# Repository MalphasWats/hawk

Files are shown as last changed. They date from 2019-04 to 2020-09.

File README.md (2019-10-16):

# hawk
Small ARM dev board based on ATSAMD10.

This repository takes a step-by-step look at creating a simple ATSAMD10-based dev-board using KiCAD.

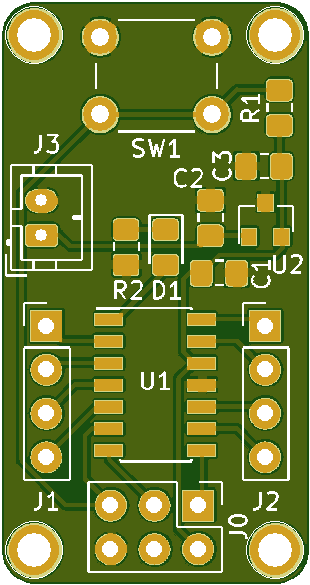
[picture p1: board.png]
Board


## Contents

### Designing the PCB

1. [Getting Started - Creating a Schematic.](https://github.com/MalphasWats/hawk/blob/master/articles/creating-the-schematic.markdown)
2. [Adding Battery Power.](https://github.com/MalphasWats/hawk/blob/master/articles/adding-battery-power.markdown)
3. [Footprints & Net-lists.](https://github.com/MalphasWats/hawk/blob/master/articles/footprints-and-netlists.markdown)
4. [Creating a PCB.](https://github.com/MalphasWats/hawk/blob/master/articles/creating-a-pcb.markdown)
5. [Aside: Designing a Board Outline.](https://github.com/MalphasWats/hawk/blob/master/articles/designing-board-outline.markdown)
6. [Component Layout.](https://github.com/MalphasWats/hawk/blob/master/articles/component-layout.markdown)
7. [Laying Traces.](https://github.com/MalphasWats/hawk/blob/master/articles/laying-traces.markdown)
8. [Filled Zones.](https://github.com/MalphasWats/hawk/blob/master/articles/filling-zones.markdown)
9. [Silkscreen.](https://github.com/MalphasWats/hawk/blob/master/articles/silkscreen.markdown)
10. [PCB Manufacture.](https://github.com/MalphasWats/hawk/blob/master/articles/pcb-manufacture.markdown)

### Assembly
11. [Assembly.](https://github.com/MalphasWats/hawk/blob/master/articles/assembly.markdown)

### Programming

...

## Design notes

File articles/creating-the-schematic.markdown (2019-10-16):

# Creating the schematic

I'm using KiCAD for this project. It's free and it more than does the job. I'm sure people have various Strong Opinions on which EDA software is the best, but I'm also sure that they're all wrong, regardless of which one they think is best.

Open up KiCAD and create a new project:

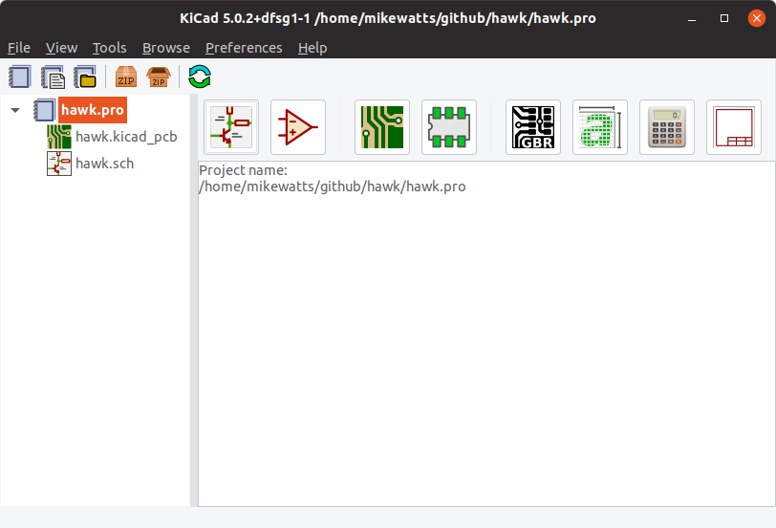
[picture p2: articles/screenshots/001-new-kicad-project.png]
New KiCAD Project


I've named this project *Hawk*. My projects generally get named when I make them a repository in [GitHub](https://github.com/MalphasWats). I think I wanted a name that suggested 'dev-board' and had recently read a tweet about Tony Hawk, who is a skate*board*er. Welcome, reader, to the inside of my brain.

We'll start by creating a Schematic for our board:

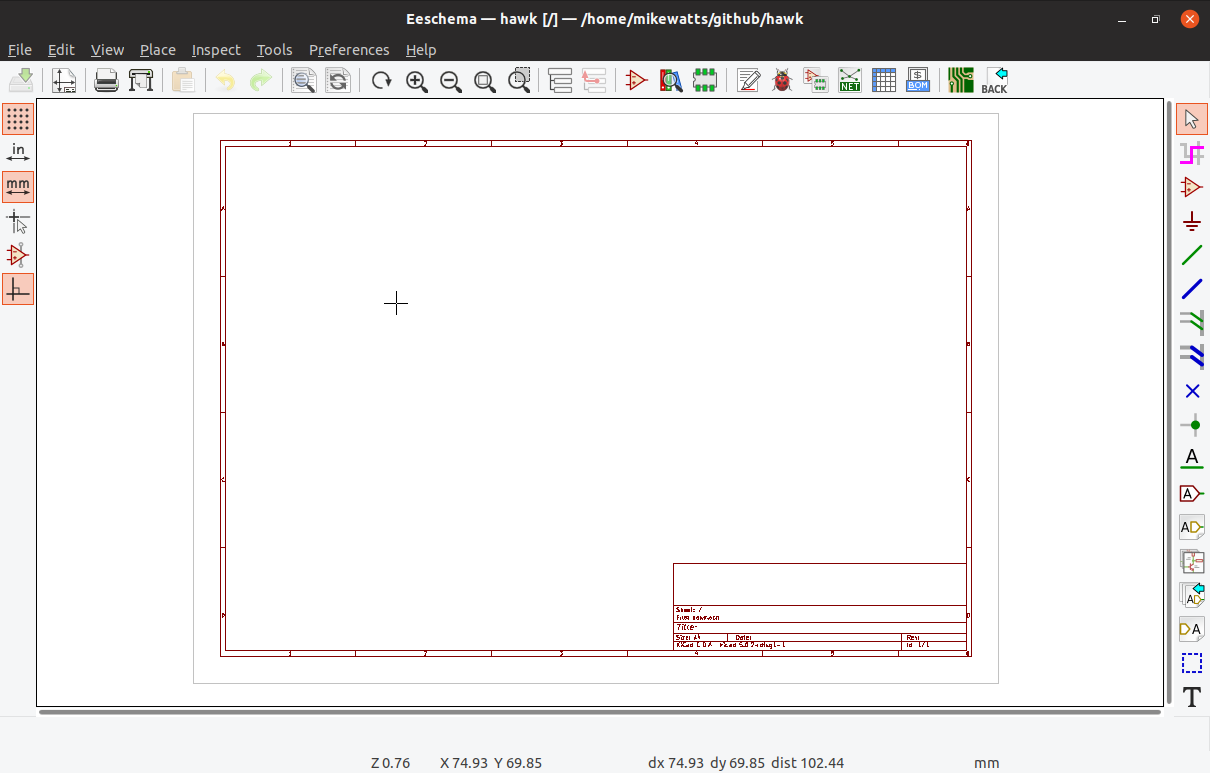
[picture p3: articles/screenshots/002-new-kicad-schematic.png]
New KiCAD Schematic


Ok, we have a nice blank schematic. Press the *A* key to add a *symbol*. This brings up the symbol browser:

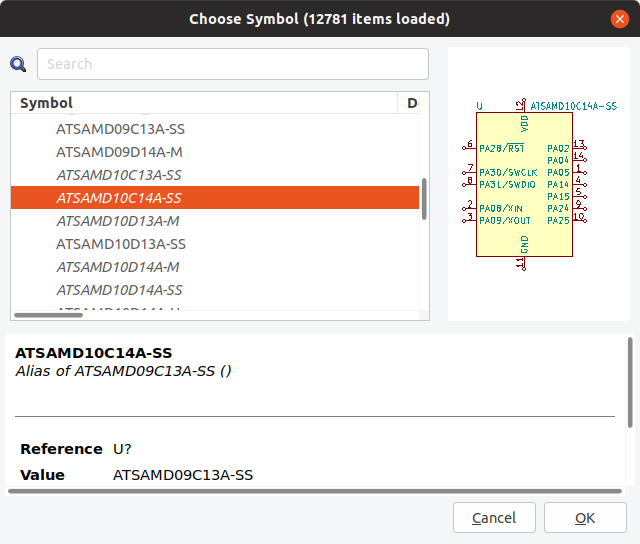
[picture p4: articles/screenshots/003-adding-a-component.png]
Symbol Browser


Now, this is where things go immediately off the rails - the basic installation of KiCAD does not have a symbol for the Microcontroller we're using in this project. You can download these symbols from the [KiCAD GitHub Symbol Library](https://kicad.github.io/symbols/).

Once you've downloaded the correct library [ (MCU Microchip SAMD) ](https://kicad.github.io/symbols/MCU_Microchip_SAMD), choose *Manage Symbol Libraries...* from the *Preferences* menu, then click the *Browse Libraries...* button to add the downloaded library.

Now you should be able to find the ATSAMD10C14 symbol shown in the screenshot. This is the only 'non-standard' component we'll be using for this project.

Double click the symbol in the list and the browser window closes and the symbol is attached to your mouse. Click anywhere on the page to add the symbol to the schematic.

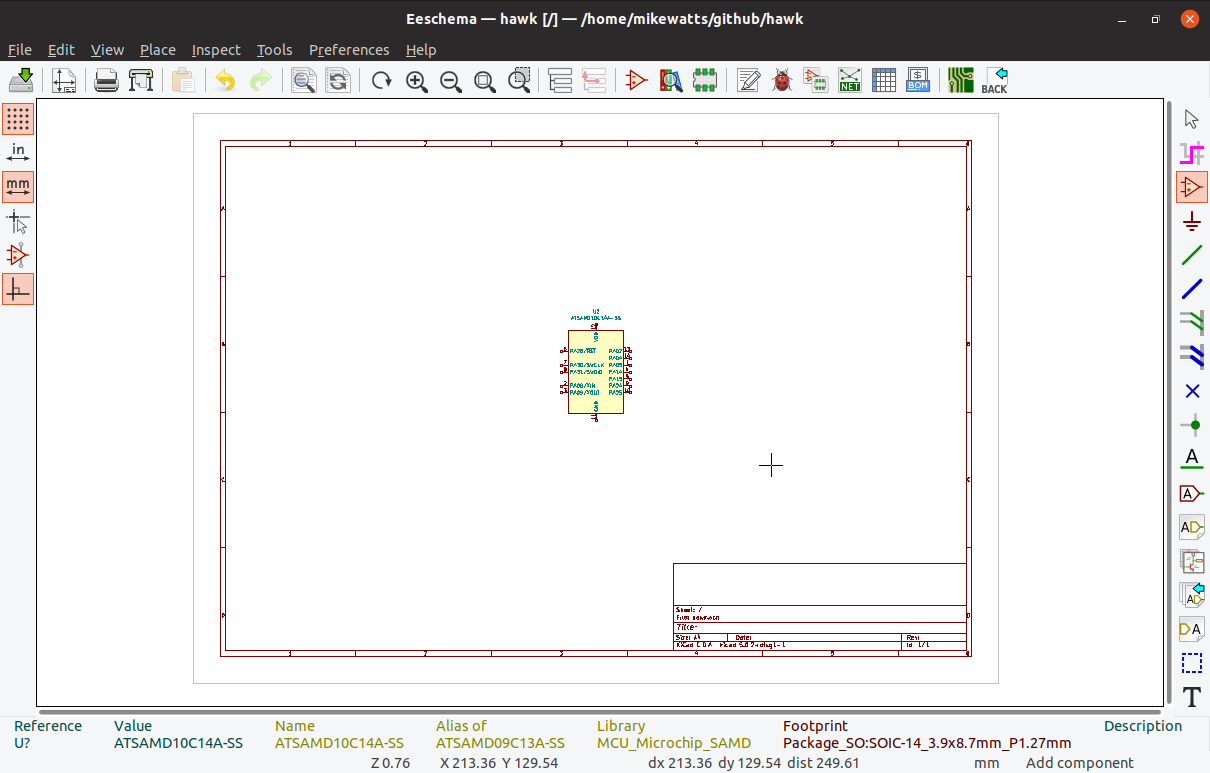
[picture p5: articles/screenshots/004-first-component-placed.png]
Symbol Placed


Congratulations, you've made a schematic! It doesn't really do very much yet though. Let's add a bypass capacitor for the MCU IC.

When we pressed *A* earlier, we selected the *Place Symbol* tool, that means we just have to click anywhere on the schematic page to add another symbol. KiCAD puts passive components like capacitors and resistors in the *Devices* section of the symbol library browser:

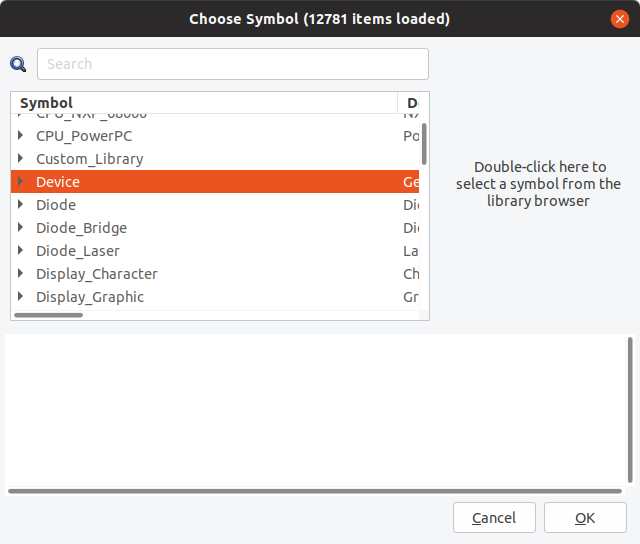
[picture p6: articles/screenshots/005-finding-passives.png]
Finding Passives


Expand it and find the *C* symbol (I prefer to use the *C_Small* version, but either will do.).

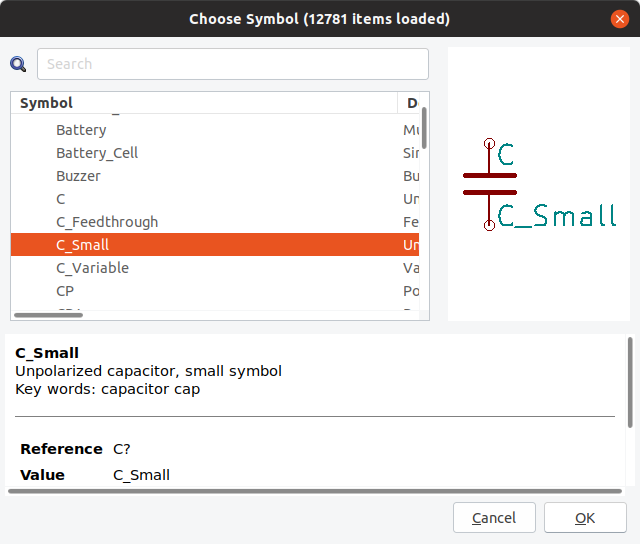
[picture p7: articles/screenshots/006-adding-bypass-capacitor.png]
Bypass Capacitor


Double click to select the symbol then click where you want to place it on the schematic page:

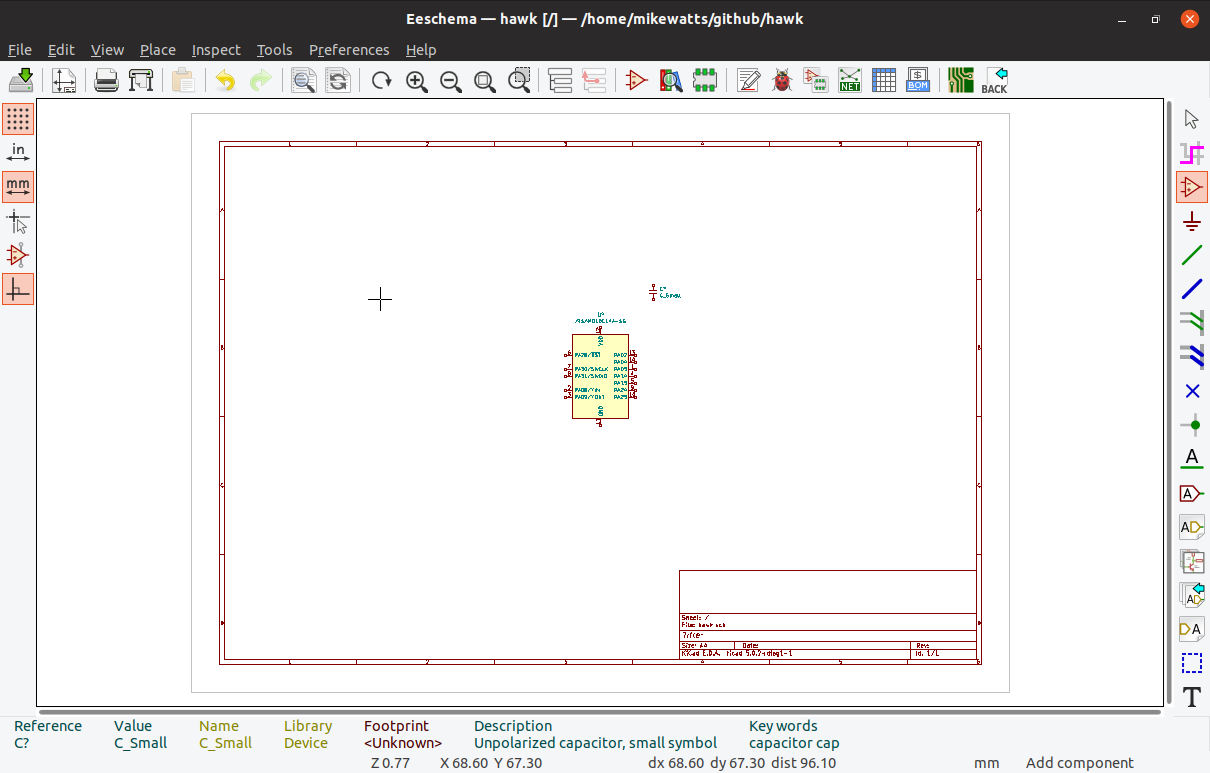
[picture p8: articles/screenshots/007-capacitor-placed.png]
Capacitor Placed


I tend to use 0.1uF capacitors for bypassing ICs, I'm sure the internet is replete with screeds on why a different value is better. Frankly, most of my projects work without even bothering to solder the thing to the board.

Bring your mouse over the capacitor *Value Field*, if you chose the regular symbol version it will just be a capital *C*, otherwise it'll say *C_Small*. With your mouse over the field, press the *E* key on your keyboard to bring up the field editor.

Enter the new value for your capacitor and press *OK*.

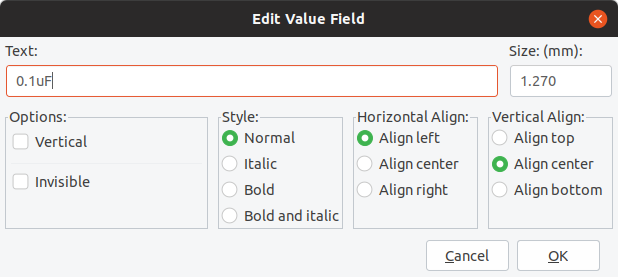
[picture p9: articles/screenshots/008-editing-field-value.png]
Edit the field value


We'll connect the capacitor to the power net next. Press *P* on the keyboard to bring up the *Power Symbol Browser*.

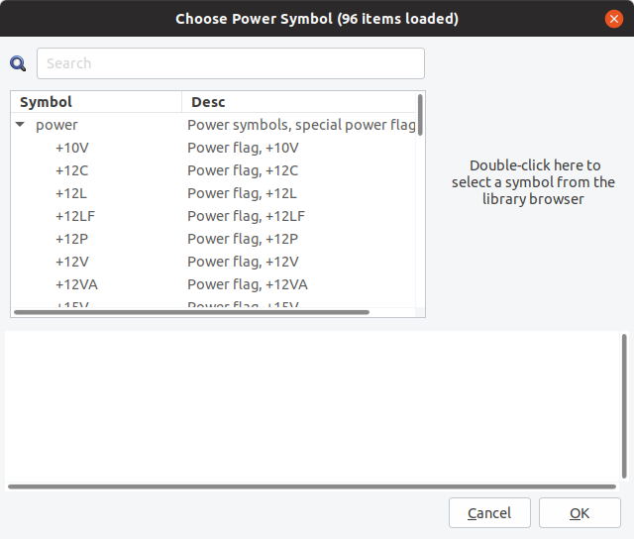
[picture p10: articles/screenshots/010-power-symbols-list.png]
Power Symbol Browser


Expand the *power* list and scroll down to find +3V3. Double click it to select.

Now, instead of just clicking on an empty spot on the schematic, attach the symbol to the lead sticking out of the top of the capacitor symbol.

Press *P* again and scroll down to place a *GND* symbol. Attach it to the bottom lead of the capacitor symbol.

Once you have symbols placed on the schematic, you can duplicate them by hovering over them and pressing the *C* key. Duplicate the +3V3 symbol and the GND symbol to attach them to the relevant leads of the MCU.

You'll also notice in the screenshot below that I've moved the labels for the MCU. You can do this by hovering your mouse over them and pressing *M*.

*M*, *C*, *A* and *P* are super useful shortcuts for laying out schematics. They become muscle memory quite quickly.

Using the *scroll-wheel* on the mouse lets you zoom in so  you can actually see what you're doing. As far as I've managed to work out, zooming like this centres the zoom wherever your mouse pointer is.

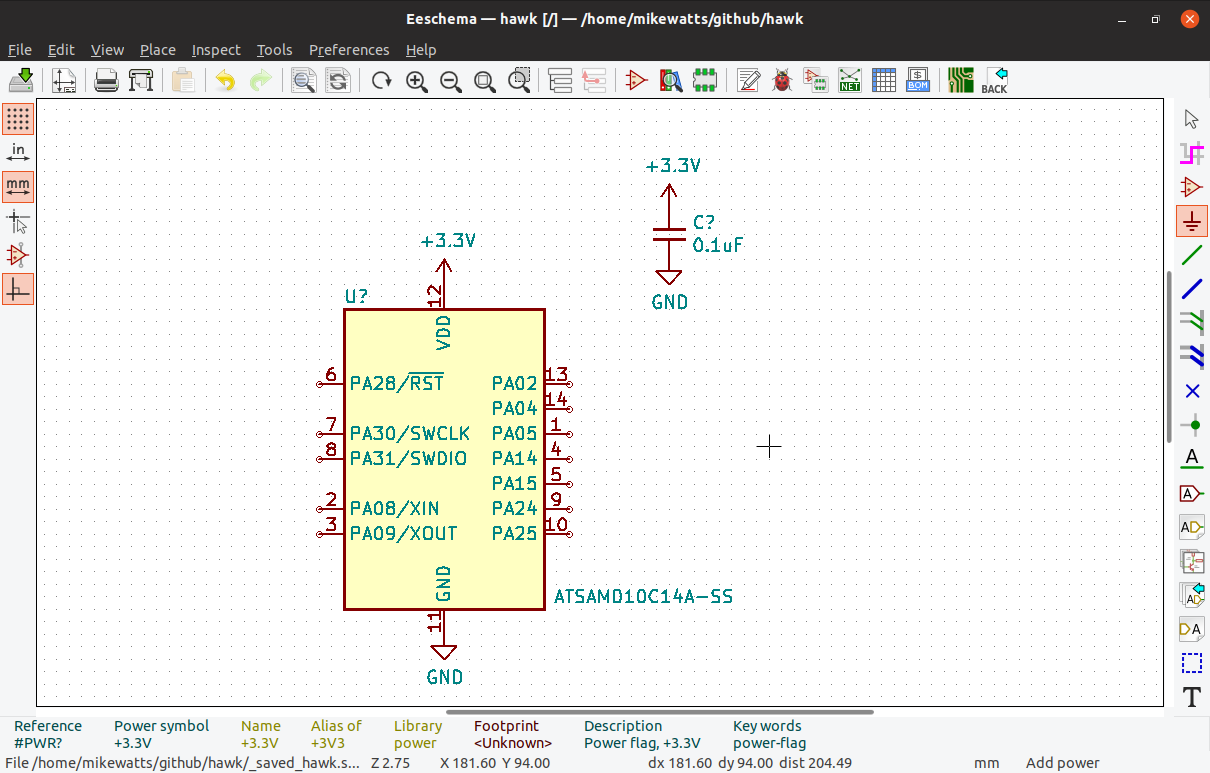
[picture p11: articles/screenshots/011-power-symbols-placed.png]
Place Power Symbols


Notice that the capacitor and MCU aren't connected directly, we've just connected them to the power net, it'll be up to us to place them sensibly on the PCB so that the capacitor can do its job.

Ok, let's create a reset circuit. First, we want to add a *pull-up* resistor to the MCU's reset pin. If we simply leave the pin floating, the MCU could behave strangely as our circuit gets subjected to electromagnetic interference.

We'll start by labelling the reset pin. I use *global* labels because I think they make a schematic more readable. Choose *Global Label* from the *Place* menu and then click on the end of the lead for *pin 6* to bring up the label pane:

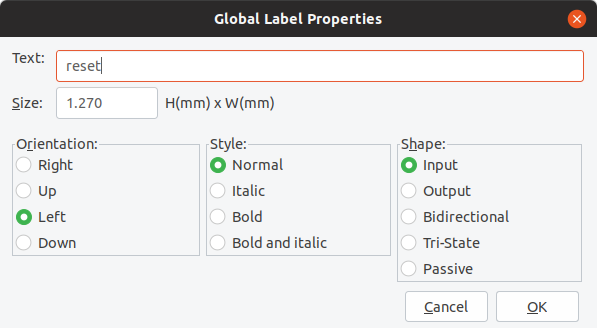
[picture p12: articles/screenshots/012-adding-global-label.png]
Adding a global label


Give the label a sensible name and make sure *Left* is chosen for *Orientation*. Click *OK* and then click the mouse on the end of the *pin 6* lead to attach the label to it.

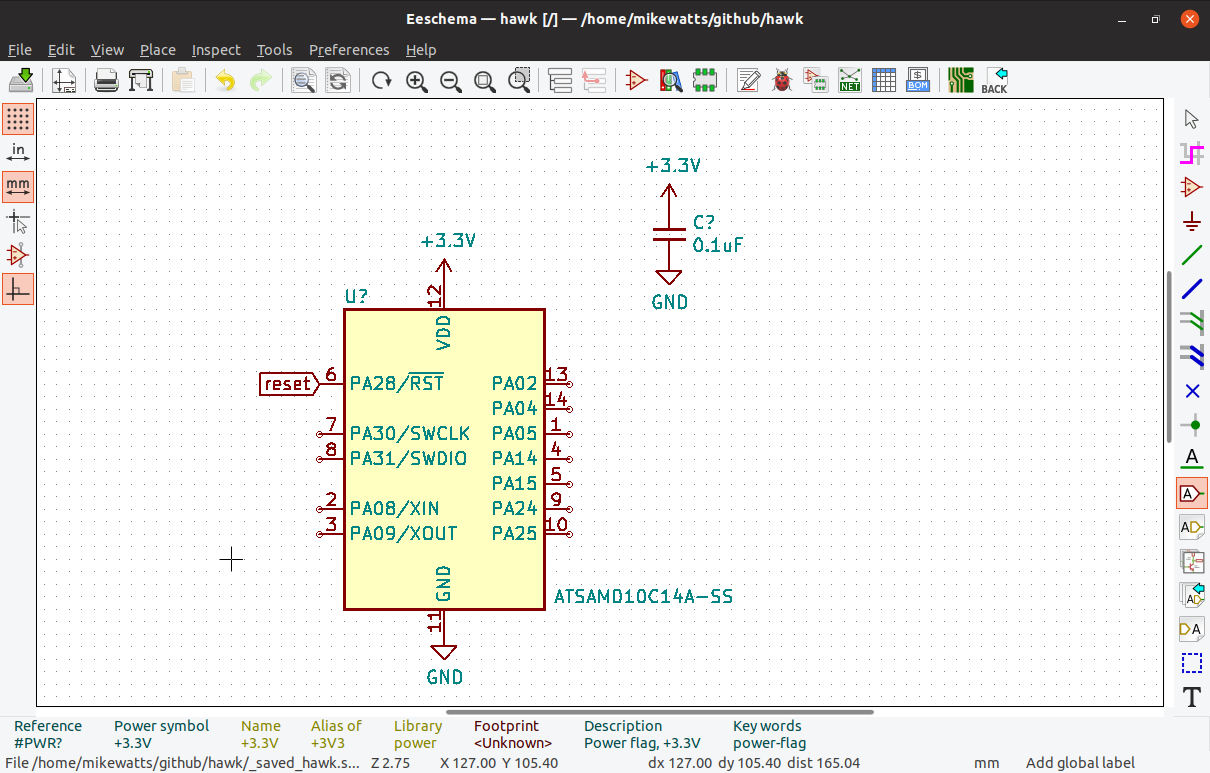
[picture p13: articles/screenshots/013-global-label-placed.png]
Place the label


Whilst we're at it, let's add 2 more labels for the programming pins, we're already in *Label Place mode* so we just need to click on the schematic to add a new label:

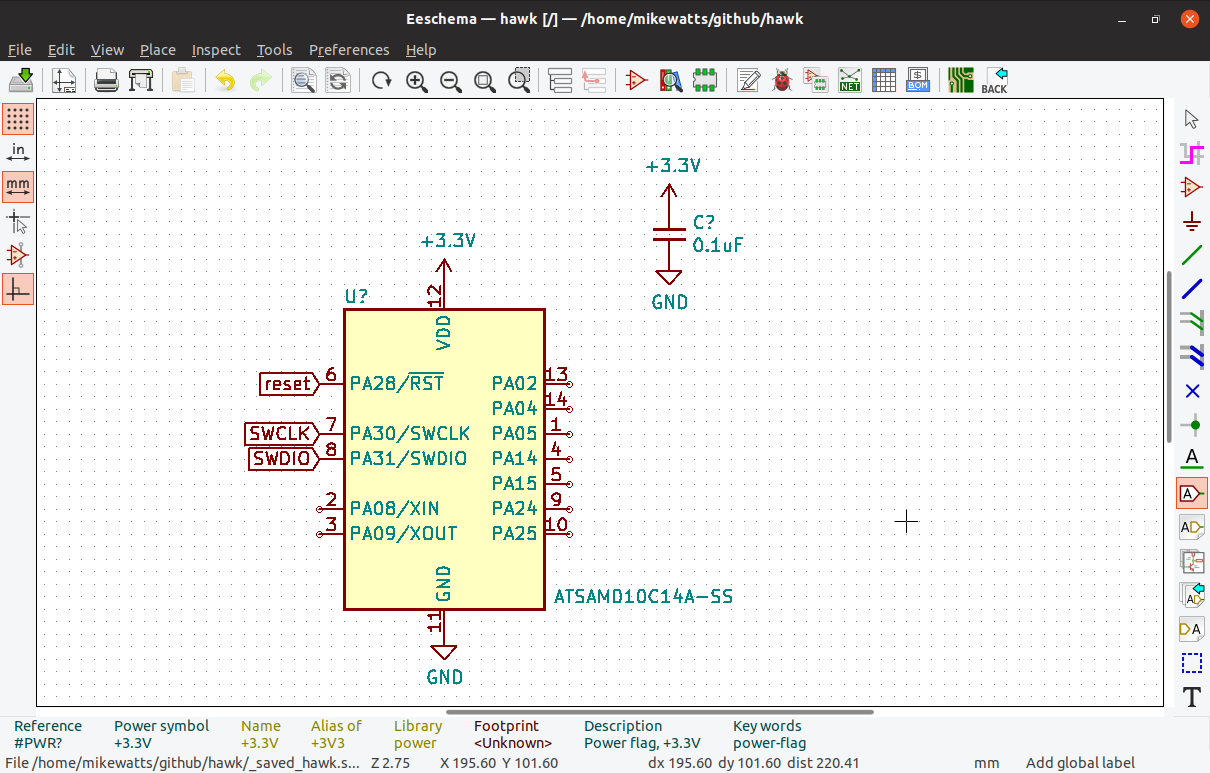
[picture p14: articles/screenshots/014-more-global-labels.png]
Programming pin labels
.

Next let's add the pull-up resistor. Press *A* to go back into symbol placing mode and bring up the symbol browser. You'll find it in the *Devices* section again, called simply *R*.

Click to place it, then use the *C* shortcut to copy the 3V3 power symbol and attach it to the top lead of the resistor. Use *C* again to copy the *reset* label from the MCU pin 6.

With the *reset* label attached to the mouse, press the *R* key to rotate it 90 degrees. Press the *R* key until the label is pointing *up* and attach it to the bottom lead of the resistor.

Finally, hover over the bottom *R* label, press *E* and add a suitable resistance value - I tend to use 10K ohm:

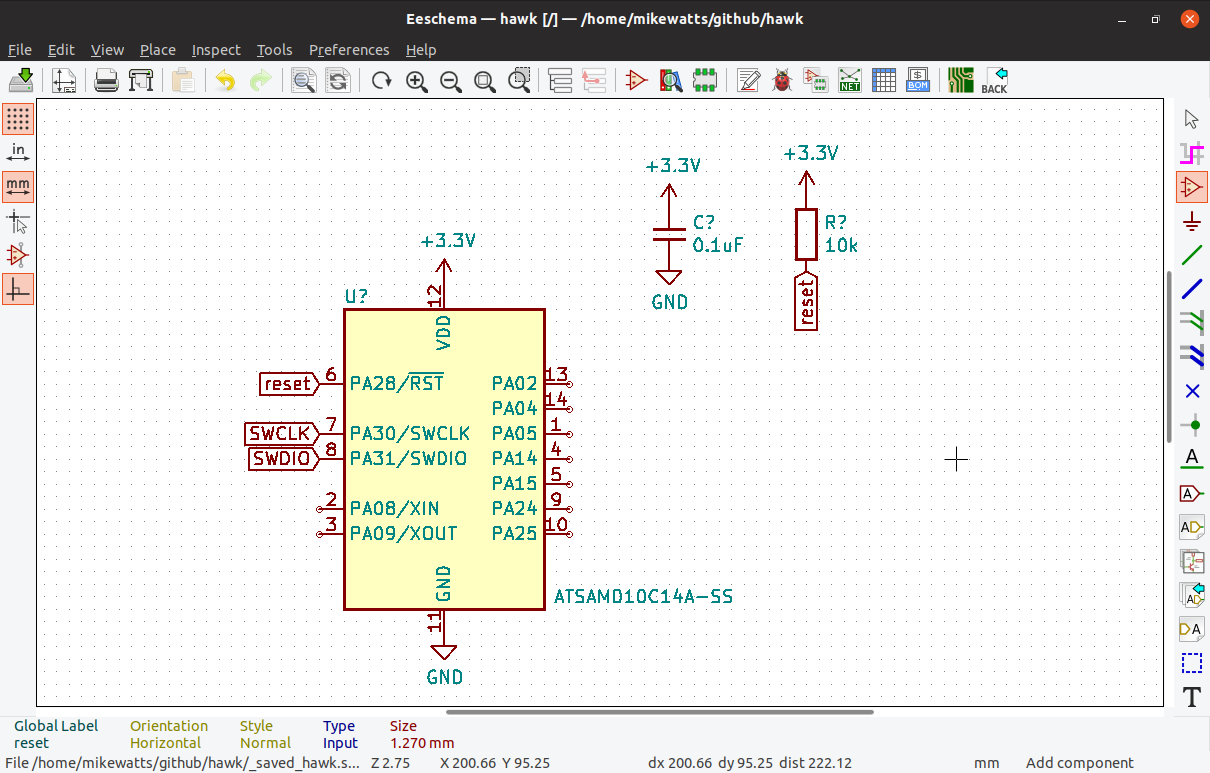
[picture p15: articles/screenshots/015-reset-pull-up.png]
Pull up resistor


Alright, we have a stable circuit for an MCU. If you look at each symbol it has a second label with the symbol designator (U, C, R) and a question mark (?). We need to annotate our schematic to give each of these a unique identifying number. You can simply hover over each one, press *E* and type it manually, and indeed sometimes that's the way you want to do it, however, there is also a tool built in that will do it for us. You can do this at any stage of development, including right at the very end, but I like to try to keep an eye on what numbers mean what and do it as I go.

Choose *Annotate Schematic...* from the *Tools* menu to bring up the annotation tool

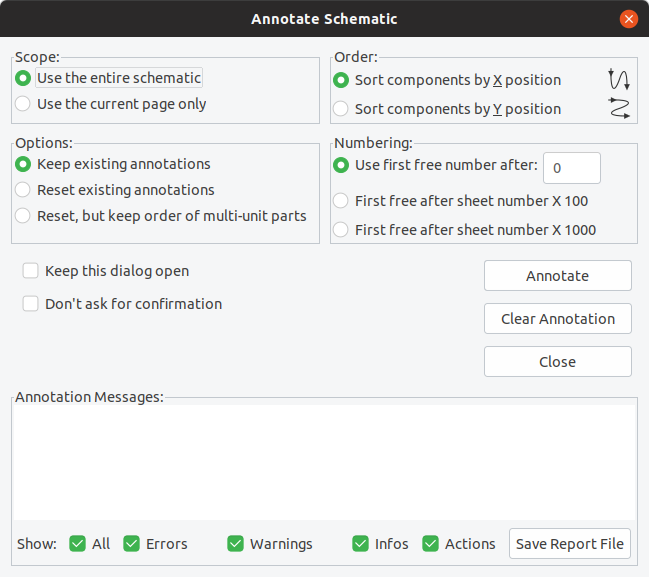
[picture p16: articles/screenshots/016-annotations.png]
Annotation tool


Default settings are fine, simply click *Annotate* to automatically annotate the schematic symbols:

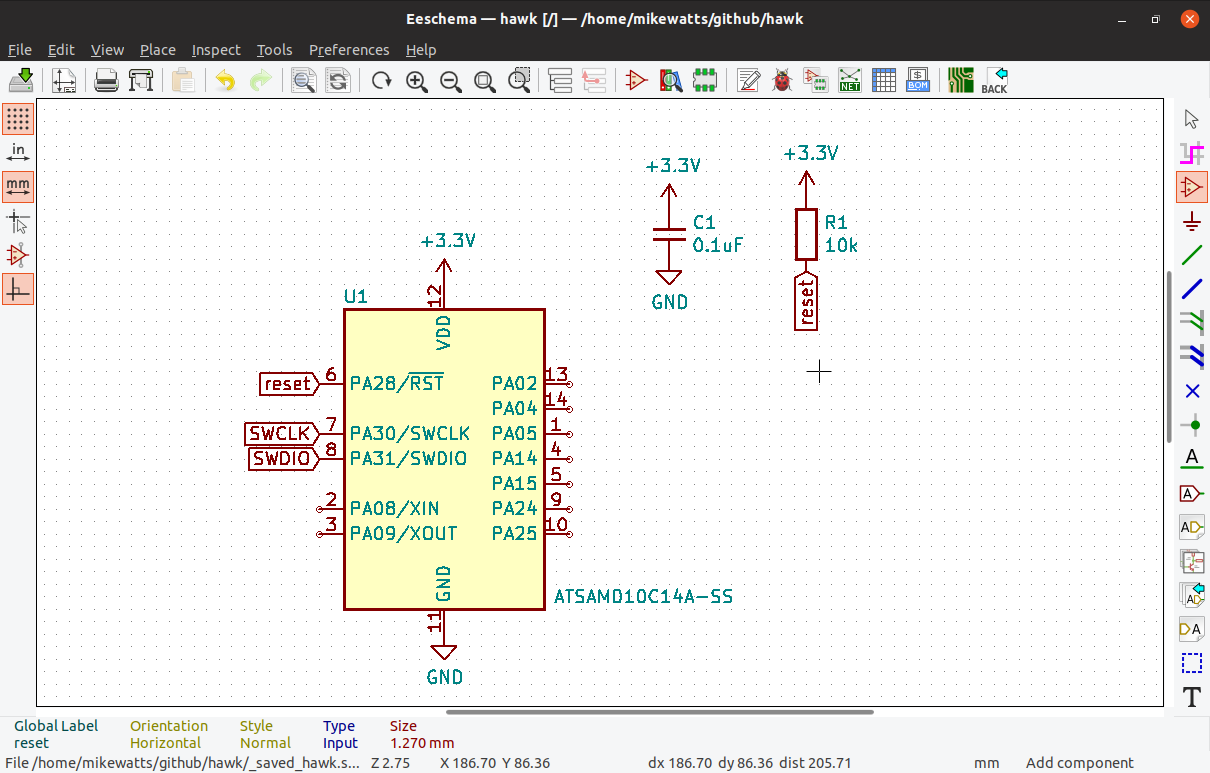
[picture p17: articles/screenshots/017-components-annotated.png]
Annotated Schematic


We get *U1*, *C1*, and *R1*.

**Now is also a good place to save the schematic if you haven't already.**

Now we'll add a button so we can reset the MCU when we're frustrated that it isn't doing what it's supposed to be because we wrote the wrong code but haven't accepted that yet.

Press *A* to add a symbol, navigate to *Switches* and find the SW_Push symbol. It doesn't really matter too much which switch symbols we use for a simple Single-pole-single-throw switch, but this is technically the *proper* one.

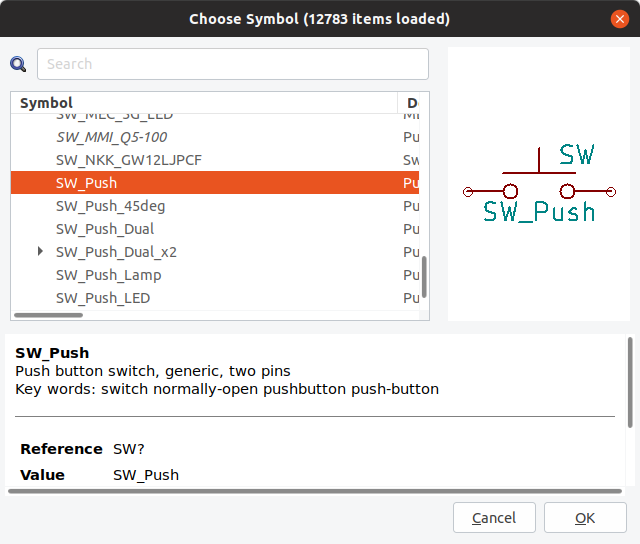
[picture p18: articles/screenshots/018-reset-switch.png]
Push Switch


Double-click to choose the symbol then click somewhere on the schematic to place it.

Use the *C* key to duplicate the *reset* label and connect it to the left-hand lead of the switch symbol.

Next duplicate a *GND* symbol from somewhere and place it *near* the right-hand lead:

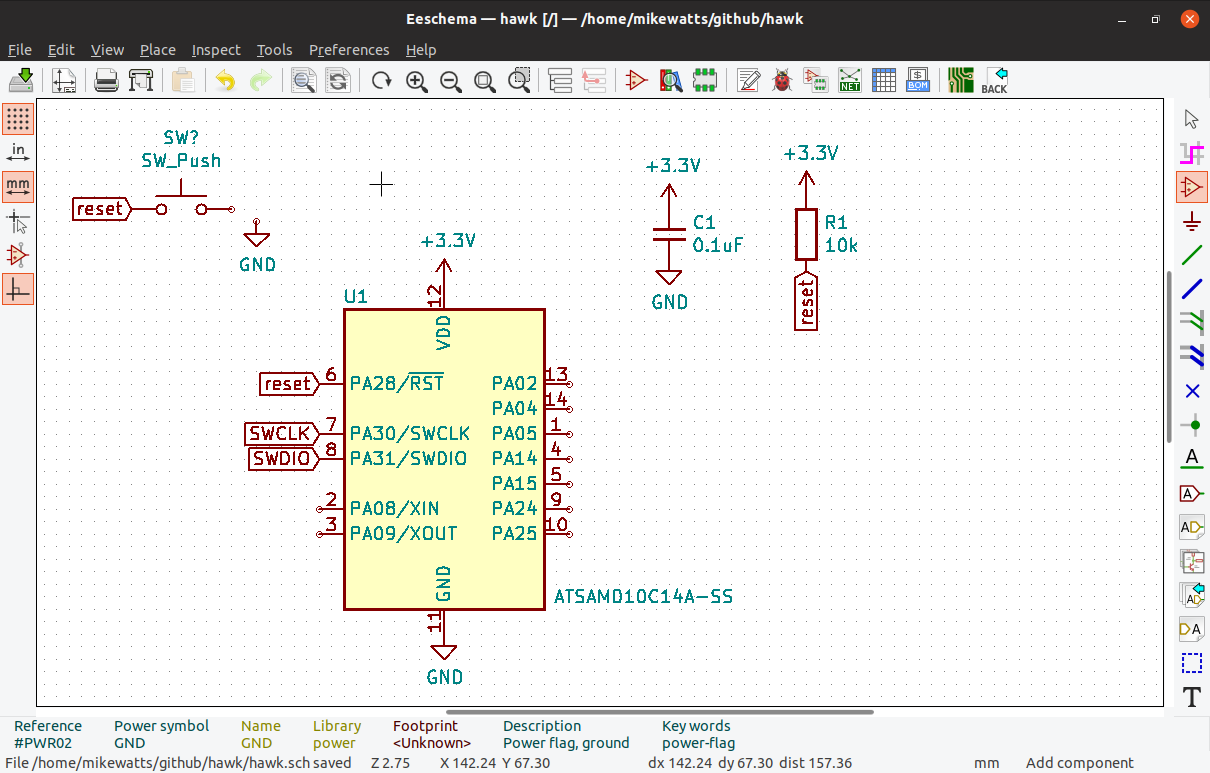
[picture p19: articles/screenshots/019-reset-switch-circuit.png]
Reset Circuit


You *could* simply connect the *GND* symbol to the switch, but I think it looks a little bit cluttered, so instead, we'll leave a little gap and use the *Wiring tool* to connect the symbols.

Press the *W* key to choose the wiring tool and then click the little circle stuck to the end of the right-hand lead of the switch symbol, then move your mouse, drawing a green wire behind and click the little circle at the top of the *GND* symbol to connect them together:

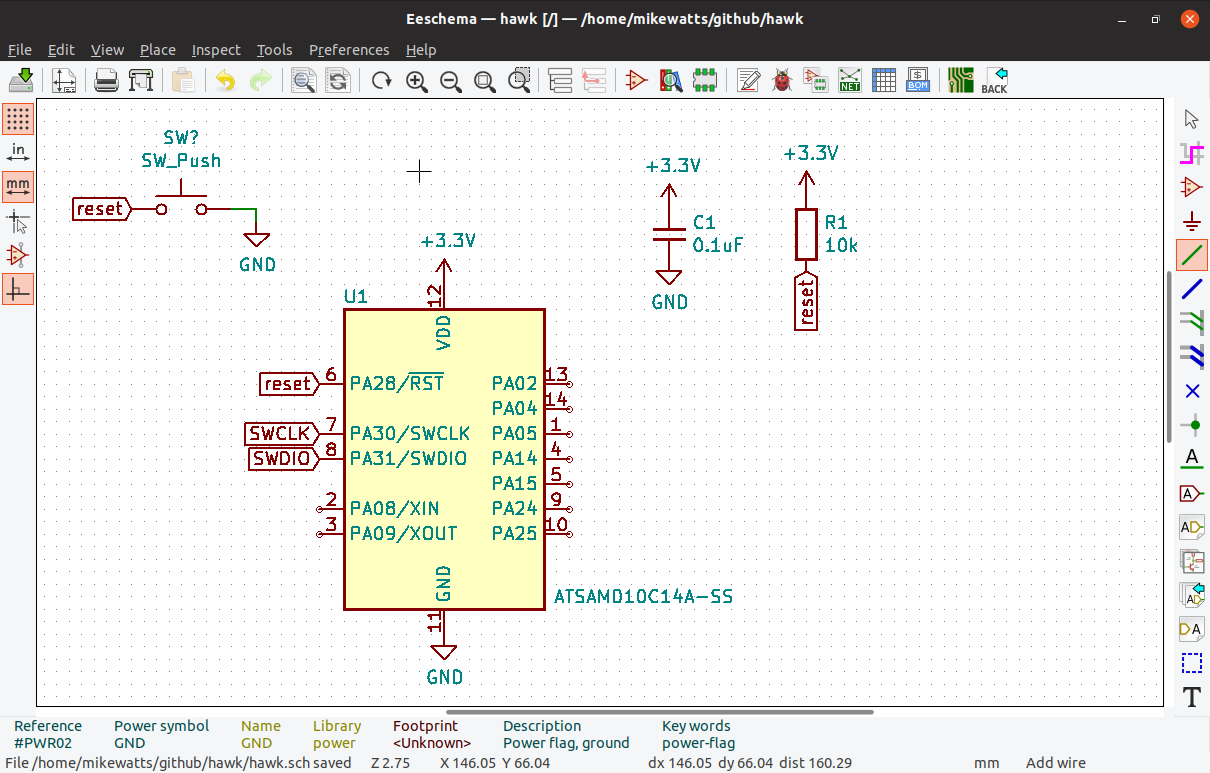
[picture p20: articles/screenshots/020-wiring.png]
Complete reset circuit


So now we have *A*, *P*, *M*, *E*, *R* and *W* shortcuts. All well worth remembering.

All development boards need an LED, otherwise how are you supposed to write a Blink program for it? Let's add one.

Start off by adding a new *Global Label*, call it *LED* and orient it *Right*:

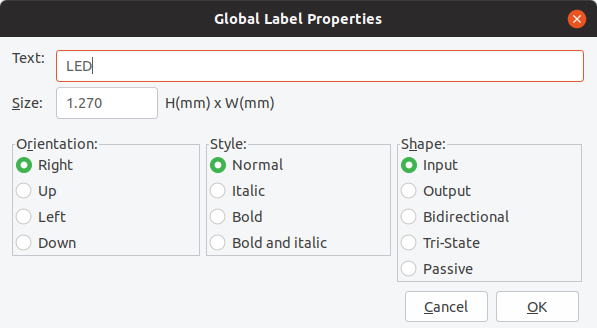
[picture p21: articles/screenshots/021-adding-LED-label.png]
LED Label


Connect it to *pin 13* of the MCU.

Next, press *A* to add an LED symbol. Whilst the symbol browser has an LED section, all the symbols in here appear to be special ones. We just want the LED symbol in the *Device* category. I prefer the *LED_Alt* version. Double click it and then place it somewhere on the schematic.

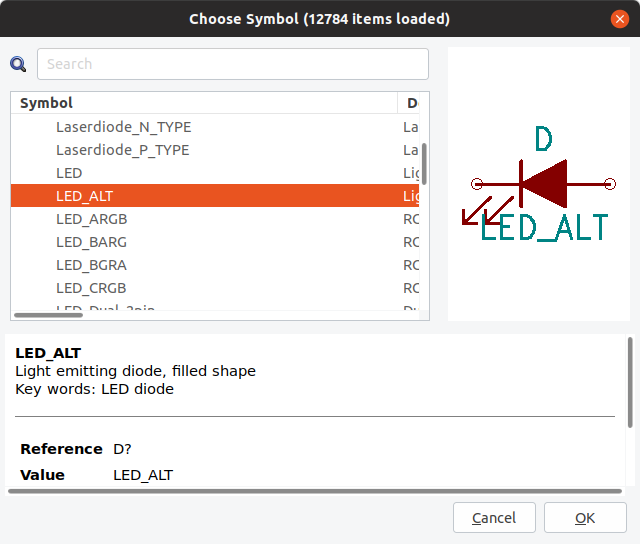
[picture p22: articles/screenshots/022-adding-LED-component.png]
LED symbol


Next, add a resistor (or duplicate the one from the reset pull up), place it near the LED symbol and edit its value to 1k. Now, duplicate the *LED* label, rotate it and connect it to the left-hand lead of the LED. Finally, duplicate a *GND* symbol and place it near the right-hand lead of the resistor:

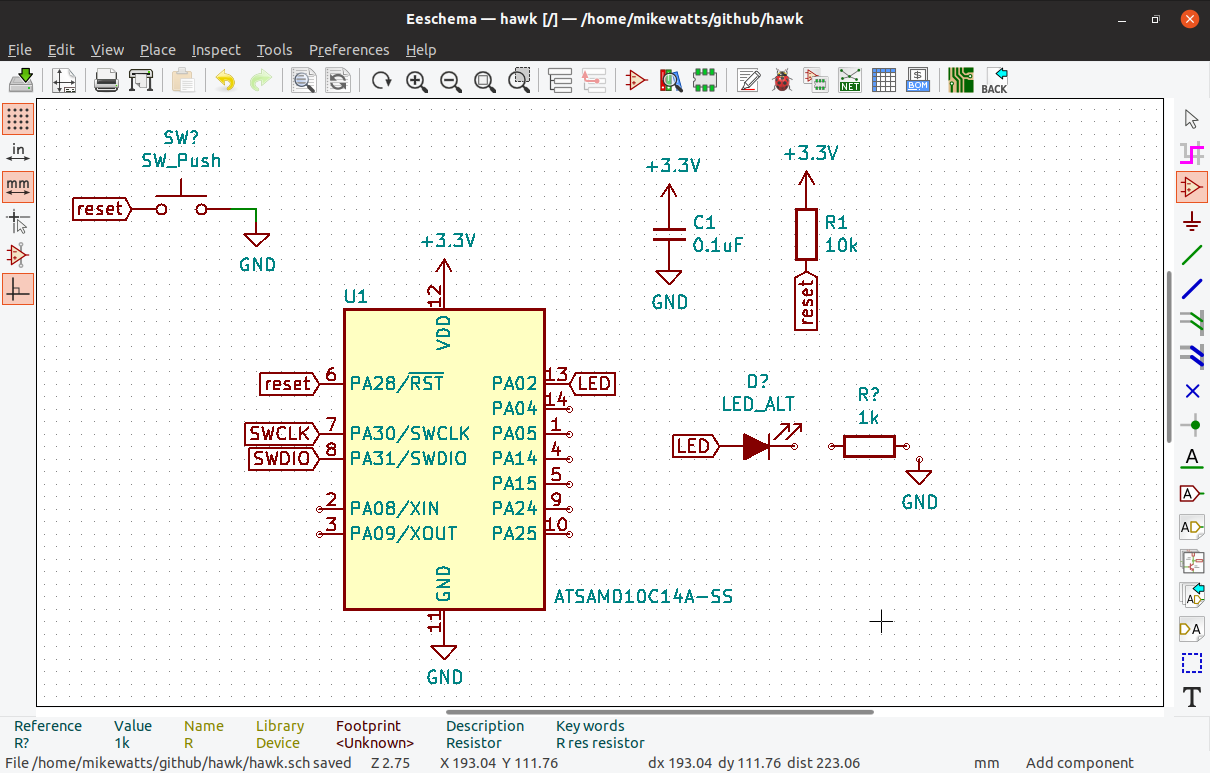
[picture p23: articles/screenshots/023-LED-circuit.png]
LED Circuit


Use the *W* key to switch to wiring mode and connect the circuit:

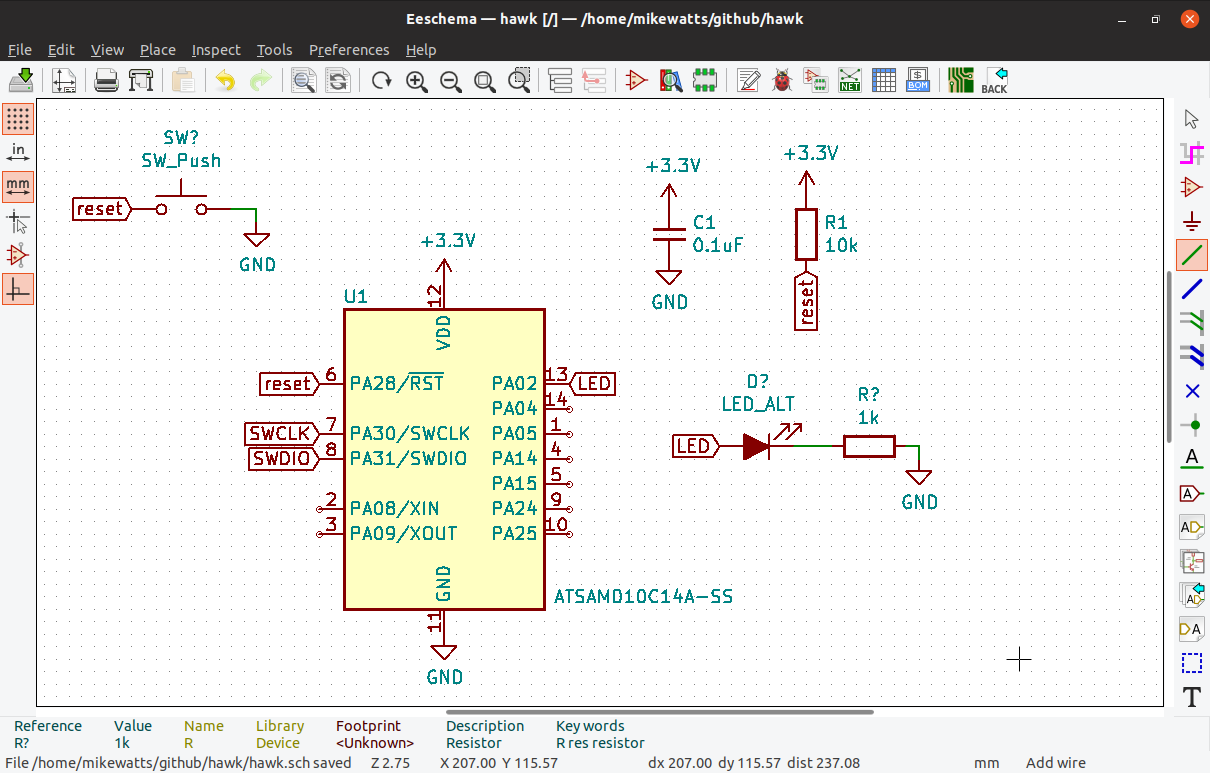
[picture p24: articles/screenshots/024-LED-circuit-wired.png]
Complete LED circuit


Now is a good point to annotate the schematic **and save it**:

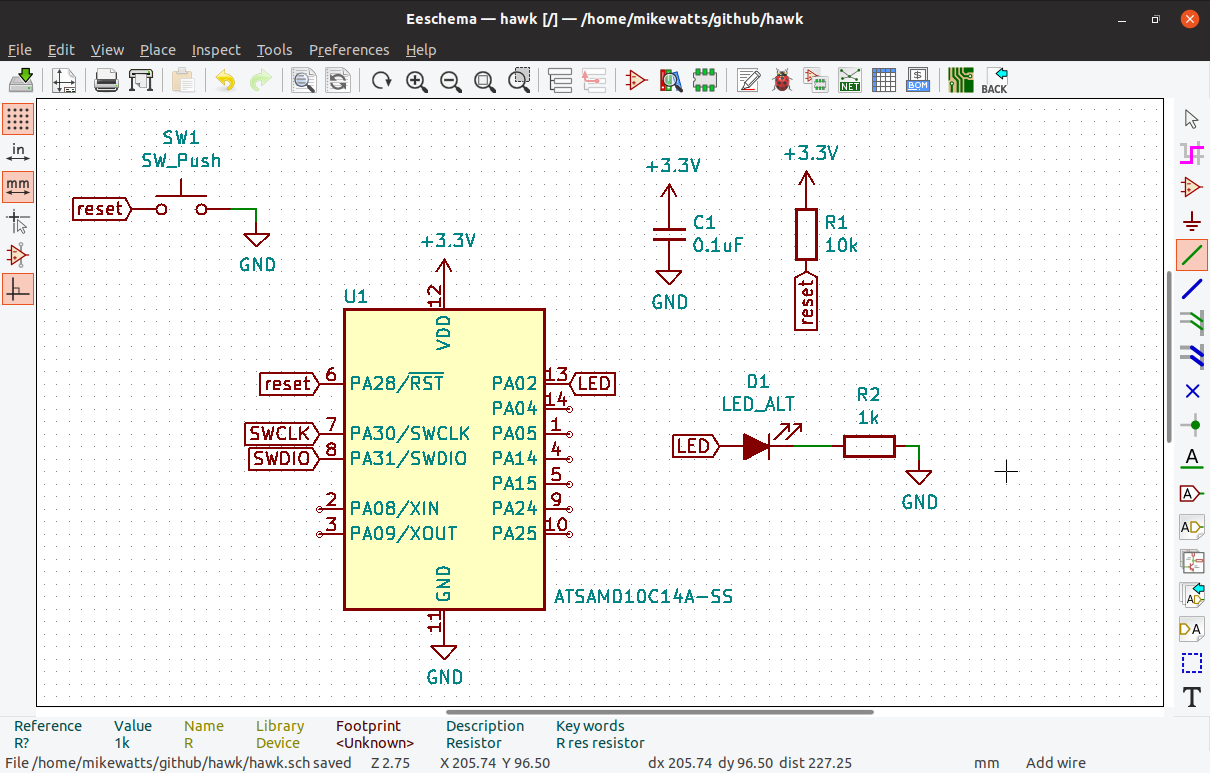
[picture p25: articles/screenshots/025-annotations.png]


We could simply stop there. We could program the MCU using one of those clip things and then we have everything we need to blink an LED, but ultimately the feeling of achievement would fade and we'd be left with more e-junk. Let's expand our circuit a little so it's useful after we've flashed a light.

We'll start off adding a programming header. I don't have one of those clip things that would fit this chip.

Press *A* to add a new symbol, expand the *Connector_Generic* category and find a 2x3 Odd/Even connector:

SWD Connector

The SAMD10 is programmed using the Single-Wire-Debug (SWD) interface, so-called because it uses just a single wire. Plus one other wire, a reset wire, power and ground. So 5 wires. There are some standard connector layouts for SWD as part of the JTAG definition, but these tend to use connectors with at least 10 pins and as many as 20. I already have a nice little 2x3 programming ribbon cable so I'm using that. The nice thing about tutorials is you're entirely free to do it your own way!

Place the connector on the schematic and rename it to something useful. Remember you can hover over the *Conn_02x03_Odd_Even* label and press *E*. I've named it *SWD_PGM*.

Place Connector

Earlier we created some global labels for *reset*, *SWDIO* and *SWCLK*. Duplicate those, along with a *+3V3* and a *GND* and connect them to the connector leads as below:

Connect programming header

I've used this layout because it's similar to the ISP layout for programming AVR via SPI. This helps me remember what each pin is for.

Next up, let's add some headers for some of the GPIO pins. Use *A* to add 2 generic 1x4 connectors:

Generic Connector

Place one and name it:

Place Connector

Duplicate and rename it:

Duplicate connector

I wanted to have an extra visual queue for which connector is which, so I mirrored the second one so the leads pointed the other way. Hover your mouse over the symbol and press *E*, choose *Mirror around y-axis* from the *Aspect* section:

Mirror Connector

Create some more *global labels*:

GPIO Labels

One for each of the spare MCU pins:

GPIO Labels placed

Now duplicate each one and connect them to the generic connector pins:

GPIO Labels connected to connector

We've reached another good point to annotate and **save the schematic**

Annotate schematic

One thing that bugged me about the annotations for the connectors was that one of the GPIO connectors was *J1*, the programming connector was *J2* and the other GPIO connector ended up with *J3*. If you're more normal this probably doesn't bother you.

To edit the *Reference field*, hover over it with your mouse and press *E*.

Change reference field

You can change the numbers to make things more sensible.

Updated Annotations

We've also reached the end of this part of the tutorial. Again, at this stage we could make the PCB and we'd have a board that we could actually use, but there are a few more things I want to add first.

## Caveats

It's worth noting at this point that there are a few issues with the schematic. I made the thing and took all of the screenshots in one go with a view to creating this tutorial rather than a super-awesome-development-board. Afterwards I was reading the [SAMD10 Datasheet](http://ww1.microchip.com/downloads/en/devicedoc/atmel-42242-sam-d10_datasheet.pdf). Section 36 has some suggestions for a reset circuit (p 854) which includes an extra resistor to control the discharge of the bypass capacitor when the reset pin is grounded. It also notes that the reset pin has an internal pull-up resistor so doesn't necessarily need an external one. Personally I think it's a good habit to get into, if only for reset pins.

It also strongly recommends (p 858) that the *SWCLK* pin has a pull-up resistor added to it to prevent noise. If we were making a commercial product, we'd probably go back and fix that. I know from previous experiments with this chip though that it should still work in most cases without it.

I also noticed that there's no easy way to supply power to any theoretical breadboard we might plug this device into. Although we could actually use the *+3V3* and *GND* pins from the programming connector if we needed to, this wouldn't be ideal. To fix this, we could instead make the 1x4 GPIO connectors into 1x5 and add connections to the power net.

This is what the updated schematic for these fixes might look like:

Updated Schematic

The rest of the tutorial however will still use the older version. I've ordered the boards to be made like this too, so we can actually find out how well it works anyway!

[001]: screenshots/001-new-kicad-project.png
[002]: screenshots/002-new-kicad-schematic.png
[003]: screenshots/003-adding-a-component.png
[004]: screenshots/004-first-component-placed.png
[005]: screenshots/005-finding-passives.png
[006]: screenshots/006-adding-bypass-capacitor.png
[007]: screenshots/007-capacitor-placed.png
[008]: screenshots/008-editing-field-value.png
[009]: screenshots/009-adding-power-symbols.png
[010]: screenshots/010-power-symbols-list.png
[011]: screenshots/011-power-symbols-placed.png
[012]: screenshots/012-adding-global-label.png
[013]: screenshots/013-global-label-placed.png
[014]: screenshots/014-more-global-labels.png
[015]: screenshots/015-reset-pull-up.png
[016]: screenshots/016-annotations.png
[017]: screenshots/017-components-annotated.png
[018]: screenshots/018-reset-switch.png
[019]: screenshots/019-reset-switch-circuit.png
[020]: screenshots/020-wiring.png
[021]: screenshots/021-adding-LED-label.png
[022]: screenshots/022-adding-LED-component.png
[023]: screenshots/023-LED-circuit.png
[024]: screenshots/024-LED-circuit-wired.png
[025]: screenshots/025-annotations.png
[026]: screenshots/026-programming-connector.png
[027]: screenshots/027-programming-connector-placed.png
[028]: screenshots/028-programming-connector-labelled.png
[029]: screenshots/029-GPIO-connector.png
[030]: screenshots/030-GPIO-connector-placed.png
[031]: screenshots/031-GPIO-connector-duplicated.png
[032]: screenshots/032-GPIO-connector-mirrored.png
[033]: screenshots/033-GPIO-labels.png
[034]: screenshots/034-GPIO-labels-placed.png
[035]: screenshots/035-GPIO-labels-duplicated.png
[036]: screenshots/036-connectors-annotated.png
[037]: screenshots/037-editing-connector-annotations.png
[038]: screenshots/038-connector-annotations-edited.png

[038-5]: screenshots/038-updated-schematic.png

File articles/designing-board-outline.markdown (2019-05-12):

# Desiging a Board Outline

This part explores how to create a board outline using [OpenSCAD](https://www.openscad.org/), however, it's not going to be a tutorial on how to use OpenSCAD, there are loads of those and they do a much better job than I can. You don't *need* to do it this way at all, and in fact, on the face of it, it doesn't really bring any benefit to what we're doing in this short KiCAD tutorial. However, I've found it to be incredibly useful when I'm designing a board that I want to also design a laser-cut or 3d-printed case for later. As ever, I'm *sure* there are other ways to do this, there might even be *better* ways to do it, but I like this one.

Open up a new SCAD project:

OpenSCAD

Let's start off with a *square* - openSCAD can be used to design both 2D and 3D objects, and in our case we want to defind a 2D cut in the PCB material.

We're making a small board, so lets draw our 'square' (I don't know why they called the function *square* and not *rectangle*) 16mm wide by 32mm long. Press the F5 key to quick-render it:

a square

Next let's give it rounded corners. The minkowski function takes a shape and applies it all around the edge of another shape. This has the effect of making the original shape bigger by the size of the added shape. To apply a rounded corner with a radius of 2mm to our board shape, we need to minkowski it with a circle with radius of 2mm. If we want to keep our board the same width and height, we also need to decrease these values by 2:

rounded corners

That's it! Everything we've done here is entirely achievable (and arguably easier) in PCBnew itself, however, that's mostly because our board shape is very simple and small.

We need to export this drawing as a *.dxf* file, but first we need to render it. Press *F6* to render the shape, then choose *Export > Export as dxf...* from the *File* menu and save the .dxf file in the project folder.

Next, switch back to PCBnew and choose *Import > DXF File...* from the *File* menu. Select the file you just saved, then make sure *Edge.Cuts* is selected from the *Graphic Layer* dropdown and click *OK*.

Import DXF

The shape we just drew will now be attached to your mouse. Click somewhere on the PCB to place it:

Place outline

All of the footprints we imported earlier will need to be placed *inside* this shape.

Let's extend our board design slightly and add some screw holes. Switch back to OpenSCAD. We can use the *difference()* function to subtract one shape from another. Let's place a 2mm screw hole:

Screw hole

Now let's *translate* that hole into a corner:

Screw hole placed

finally, duplicate the hole and put one in each corner:

4 holes

**re-render the shape by pressing *F6*** and then export it as a .dxf file again. OpenSCAD works a little counter-intuitively when it comes to rendering and will export whatever the last *F6* rendered shape is.

Switch back to PCBnew and import the .dxf file, but *this* time, place it on the *Eco1.User* layer - this layer is useful for comments and notes and anything that won't make it onto the final board - adding the screw hole outline here gives us guides to add the *actual* holes later:

Import .dxf

Once you import the .dxf file, the outline will be attached to your mouse. Here's where we need to take a little more care: we want the main outline of the 'new' shape to line up with the original shape on the *Edge.Cuts* layer. To do this, you will probably need to change the *Grid Size* from the drop down at the top. In this case, I've chosen the smallest (built-in) grid size of *0.01mm*. In reality, I'm not sure many fabs are actually that accurate, but we should try our best anyway.

Line up layers

If you've placed it correctly, the outside outlines should line up perfectly and there should be 4 green circles in each corner showing where the holes can go:

screw holes placed

Again - all of this could be done happily in PCB new, *however* the .dxf file we just produced *could* be fed into a laser cutter and it could spit out a little case with perfectly aligned screw holes. It *is* also possible to export .dxf files from PCBnew too, but by using OpenSCAD we have options to create 3D models for cases and other attachments to the PCB and keep everything lined up. For a simple project like this one, designing the board shape in OpenSCAD is huge overkill, but it's a useful thing to know about and it makes my little write up here a little more unique.

[069]: screenshots/069-new-openscad.png
[070]: screenshots/070-a-square.png
[071]: screenshots/071-rounded-corners.png
[072]: screenshots/072-import-dxf.png
[073]: screenshots/073-outline-imported.png
[074]: screenshots/074-screwhole.png
[075]: screenshots/075-screwhole-placed.png
[076]: screenshots/076-4-screwholes.png
[077]: screenshots/077-import-screwholes.png
[078]: screenshots/078-screwholes-nearly-placed.png
[079]: screenshots/079-screwholes-placed.png

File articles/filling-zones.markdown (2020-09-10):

# Fill Zones

The last thing we need to do is to connect up all of the *GND* pads together. We *could* simply connect them all up using traces in the same way we did with all of the other pads. Indeed, this is how you *should* do it sometimes where you're being really careful to keep your digital signals clean and you really know what you're doing.

We don't really know what we're doing so we'll use a *filled zone*, sometimes referred to as a *copper pour*. This is a large *continuous* area of copper on the board that can be used to connect a common *net* together across the board.

Making sure the *F.cu* layer is selected, click the *Add filled zones* button in the tool bar that sits between the main pane and the layers list, then click somewhere in the main pain but *outside* of the board outline. This will bring up the zone fill options:

Zone Fill

The default settings are actually not wonderfully helpful. It took me quite a few boards to work this out. First off, select the *GND* net from the list of nets in the middle - you'll see that there's an entry for all of the various connections on our board. It usually doesn't make a lot of sense to use the others for zone fills, although sometimes it can be useful.

Now, let's check our PCB fab capabilities:

pcb capabilities

Now obviously different fabs will have different capabilities. We can see here that this one has a Minimum Width and Minimum Spacing of 3.5mil (a mil is apparently 1 one-thousandth of an inch, Metric Imperial. Eyroll Emoji.). 3.5mil is approximately 0.089mm. Changing the *Clearance* and *Minimum Width* settings to match these means that our filled zone will be able to sneak through smaller gaps and make it more likely  that everything will connect properly. You can see above that I have set them to 0.1mm just because I didn't want/need to push things right to the limit.

Click OK and you then need to complete drawing the zone. Draw a rectangle around the outside of the board outline. Clicking back on the starting point completes the zone, or Double-clicking will automatically join in a straight line from where your mouse is back to the starting point.

Ground zone

You can see that the empty space inside the board outline is now filled in red, and all of the *GND* pads should be connected to the zone.

Be careful using zones in this way. It is possible (and very common) for KiCAD not to be able to route around some traces or footprints and you can end up with *multiple, separate zones* which aren't electrically connected - for example, if the reset trace was routed too close to the edge of the board, there wouldn't be enough space for the ground zone to fill around it and the top and bottom zones *could* have been left unconnected.

Let's check everything is connected. In the top toolbar there's button with a little beetle on it, click this to bring up the Design Rules Check (DRC) window

Click the *Start DRC button*. KiCAD will check to make sure everything is connected properly and nothing is overlapping or broken.

DRC

DRC has found a problem with our board. It has noticed that the *1* pins of the switch aren't connected. This isn't *actually* a problem. The little 4-pin tactile push buttons we're using actually have those pins connected internally, but KiCAD doesn't know this and really, it's probably good practice not to rely on it when it comes to components like this. We can add a trace between the 2 pins:

Reset pins connected

If you do make this fix, you *MUST* re-fill the ground zone by pressing *b* on the keyboard. If you don't do this, the button would be shorted to ground.

Get into the habit of re-running DRC again after making changes like this. Helpfully, if you try to run DRC without re-filling any zones, it'll remind you and ask if you want to:

Refill zones

DRC OK

And here's our electrically complete board:

DRC OK

[104]: screenshots/104-pcb-capabilities.png
[105]: screenshots/105-ground-zone.png
[106]: screenshots/106-ground-zone-filled.png
[107]: screenshots/107-DRC.png
[108]: screenshots/108-connect-button.png
[109]: screenshots/109-refill-zones.png
[110]: screenshots/110-DRC-OK.png
[111]: screenshots/111-board-complete.png

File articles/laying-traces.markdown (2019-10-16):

# Laying Traces

Alright, so this is it, this is the Main Event. Laying the traces. On a board like we're making here it's not going to be *too* challenging, but there are some things we did wrong earlier that are going to bite us now (I did it on purpose!).

We'll start with the reset trace - we need to connect the reset pin on the MCU to the reset pad of the programming header. Start by pressing the *x* key. This is the shortcut for the trace tool. There's a button on the toolbar between the main pane and the layers list, but trust me, forget about it and use the keyboard shortcut.

Make sure the little blue triangle is showing that the *F.cu* layer is the currently active layer in the list on the right.

Click on the *reset* pad of the Microcontroller footprint. This starts one end of a *trace*. It also lights up all of the footprints that need to be connected:

First Trace

Your mouse now has a line attached. Move over to the *reset* pad on the programming header and click. KiCAD will try and route the trace as best it can. It's usually pretty good at it.

Trace placed

Nice, now we can do the two programming pins *SWDIO* and *SWCLK*. KiCAD should still be in trace mode, so simply clicking the appropriate pads will place the traces.

Programming Traces

Alright, now let's take a look at the GPIO pins and headers:

Ratsnest

In the previous section I mentioned the white lines connecting pads - the Ratsnest. You can see here that the lines are going from one side of the MCU across to the other. It *could* be that this is just how things are and you'd have to find a way to route the traces - have a go at connecting all 8 GPIO pins up and you'll probably get stuck because they have to cross. Because of the nature of our board, it doesn't really matter which header pins connect to which GPIO pins on the MCU, so we can make our lives much easier by rearranging the schematic.

Update Schematic

Switch back to the schematic editor and rearrange the labels to better match the orientation - this can take a bit of back and forth between the schematic and the PCB.

Updated Schematic

Regenerate the netlist:

regen netlist

and re-read it into the PCB editor

Re-read netlist

Now, here you can see that the ratsnest has updated and shows much easier to route connections:

Updated ratsnest

HOWEVER, I've had a few issues with this (it's probably related to doing the thing with netlists that you don't really need to do any more!).

Notice here that I've *actually* clicked on Pin 5 for *GPIO_4* but *GPIO_6* has been highlighted? I'm pretty sure this is a bug in KiCAD - remember previously the pad we clicked *was* GPIO_6.

Wrong netlist

It's not too much of an issue here because it stands out, but it can cause problems where the change is subtle. The only way I've found to fix it is to close PCBNew and re-open it. Eyeroll emoji.

Now we can route the GPIO pins

GPIO start routing

GPIOs Routed

Next route the battery positive terminal across to the bypass capacitor *C2* and then on to the regulator IC. We can also connect the current limiting resistor *R2* to the LED.

Battery routed

And now [draw the rest of the owl](https://knowyourmeme.com/memes/how-to-draw-an-owl).

3v Routed

Notice how we aren't routing any *GND* pads? We'll come back to that later.

Lastly, the reset button needs to connect all the way down to the reset pin on the MCU. Notice also that we can't really get directly to the pin because of all of the other traces? That's just a small taster of routing more complex boards.

Connect it right the way down to the pad on the programming header instead. It's still making an electrical connection with the reset pin. It's usually not a problem to connect things like this, but if you're working with very high-speed digital signals you need to be a little more careful - you'd want to lay your footprints out to take these contraints into account *first* and then connect everything else. The *reset* line is very much not a high-speed digital connection, so it gets routed last!

Reset routed

That's it. Our PCB is now nearly fully connected. We'll look at the *GND* connections in the next part.

[088]: screenshots/088-first-trace.png
[089]: screenshots/089-trace-placed.png
[090]: screenshots/090-programming-traces.png
[091]: screenshots/091-ratsnest.png
[092]: screenshots/092-schematic.png
[093]: screenshots/093-regenerate-netlist.png
[094]: screenshots/094-re-read-netlist.png
[095]: screenshots/095-ratsnest-updated.png
[096]: screenshots/096-GPIO-labels-updated.png
[097]: screenshots/097-clean-ratsnest.png
[098]: screenshots/098-ratsnest-wrong.png
[099]: screenshots/099-GPIO-trace.png
[100]: screenshots/100-GPIOs-routed.png
[101]: screenshots/101-batt-routed.png
[102]: screenshots/102-3v-routed.png
[103]: screenshots/103-reset-routed.png

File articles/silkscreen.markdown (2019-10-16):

# Silkscreen & Finishing Touches

This section of the guide is probably the worst part, so my apologies for that. I haven't really found a style for how I like my silkscreen to be and since it mostly doesn't affect the overall functionality of the board and I'm mostly learning how to make the things work, I tend not to put as much effort in as I should. It is part of my plan to re-visit this project and improve various aspects as part of another tutorial.

So, Silkscreen. The silkscreen on a PCB are the (usually) white characters and symbols printed that help whoever is assembling/using the board.

The first thing we'll do is switch off the *F.cu* layer so we can better see the silkscreen layer, we also have the *F.Fab* layer disabled from a previous part.

Disable Layers

Now we just hover over the silkscreen text we want to move, press *m* to move and *r* to rotate. Let's move the *J3* text:

Move J3

Repeat this and place all of the silkscreen text so that it clearly identifies each footprint.

Tidy Silkscreen

You can also add free text using the text tool on the middle toolbar.

Lastly, we'll add some holes and align them with our screwhole marks. Choose *Place > Footprint* from the menu or press *o*. Click anywhere on the board to bring up the Footprint Browser - this may take a while to load.

Add Footprint

Find the 2mm Plated Test Point footprint, double-click it to add it to the board. Using the green *Eco1.User* layer, align the inner black hole with the green rings:

Align footprint

These footprints aren't associated with any nets, and they don't appear in the schematic. That's why they have REF above them, and this will appear in the silkscreen. To remove it, hover over the text and press *e*, then change the layer from *F.SilkS* to *F.Fab*.

Hide Refs

Use *ctrl-d* to duplicate this 3 more times and place them on the remaining holes.

Duplicate screwholes

Don't forget to update the ground fill by pressing the *b* key, and re-run DRC to make sure nothing is overlapping.

And that's it! We have successfully created our own PCB! The only thing left is to send the files off to a fab to have it manufactured!

Completed Board

[112]: screenshots/112-switch-off-layers.png
[113]: screenshots/113-move-J3.png
[114]: screenshots/114-tidy-silkscreen.png
[115]: screenshots/115-add-screwhole.png
[116]: screenshots/116-align-screwhole.png
[117]: screenshots/117-duplicate-screwholes.png
[118]: screenshots/118-hide-refs.png
[119]: screenshots/119-completed-board.png
[120]: screenshots/120-check-DRC.png

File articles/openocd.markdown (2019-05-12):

1. apt install openocd (0.10.0-5)
1.1 apt remove OpenOCD
1.2 clone repo
1.3 edit src/flash/nor/at91samd.c, samd_issue_nvmctrl_command() change target_write_u16 to target_write_u32 (https://juju.nz/michaelh/post/2017/openocd/)
1.4 compile & install

2. set CPUTAPID 0x0bc11477 (wrong id, https://github.com/DeqingSun/Debug-Arduino-Zero-with-ST-Link-V2)

3. see full .cfg file

4. install gcc-arm-none-eabi

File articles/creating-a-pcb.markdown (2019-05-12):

# Creating a PCB

KiCAD is not actually *an* application, it's a collection of applications for designing electronic devices. PCBnew is the program we need to use to lay out the PCB. Open it up from the main KiCAD project window and you'll be presented with a blank PCB design:

New PCB

The first step is to import the *Netlist* we exported from our schematic. This will give us all of the footprints that we need to set out, as well as how they all connect together.

From the *Tools* menu choose *Load Netlist...*. PCBnew should automatically populate the *Netlist file* field, but just check it is pointing to the correct file that was exported in the previous step:

Read netlist

Click the *Read Current Netlist* button and PCBnew will read it in. You'll see the results from what it found in the little text area. Once the netlist has been read, click the *Close* button. You'll notice that you now have a bunch of yellow, red and blue things stuck to your mouse.

Place footprints

Click somewhere on the blank PCB to place the *footprints*. These are all of the footprints that we defined in our schematic:

Footprints placed

All of these footprints will need to be moved and connected with copper traces, but before we do that, we want to define a board outline. We can do this really simply, but I'm only going to explain that briefly here. I want to create the shape of the board using a different program.

You can safely skip that though and draw the PCB *Edge* using the tools in PCBnew. On the very right-hand side of the program window are a list of layers. These layers define all the different parts of  PCB. The shape of the PCB itself is defined by the *Edge.Cuts* layer.

Select the *Edge.Cuts* layer by clicking on it.

Next choose the *Line* option from the *Place* menu - this tool allows you to draw simple graphic lines. Click on an empty space in the PCB to start drawing a line, each subsequent click creates a line and also starts a new line. You can use this tool to draw out the shape of your PCB. Once you've joined the lines to create a complete shape, press the *Escape* key to exit drawing mode.

I'm pretty sure this is how the *vast majority* of people design the shape of their boards, however, I don't do it that way and want to talk a little about how *I* do it in the next part.

## Caveats

After I posted the first version of this page I received some feedback that exporting/importing netlists between Eeschema (the schematic layout program) and PCBnew is not the *current* way to do things.

Instead, changes made to the schematic can be brought over directly using the *Update PCB from Schematic...* option in the *Tools* menu of either program. This is definitely quicker and more straightforward, *HOWEVER*:

I often add footprints to the PCB that don't appear on the schematic. Things like screw holes or silkscreen logos. Using the *Update PCB from Schematic* option automatically removes any footprints that aren't associated with a schematic symbol - using the netlist method doesn't do this by default. Later in this guide I add screw hole footprints directly to the PCB this way.

It's easy to fix, you can just add an unconnected symbol to the schematic and associate the footprint you need to that, and this is probably the way you're *supposed* to do it, however, I'm not completely convinced this is the *proper* way, simply because for me, the schematic is a separate entity to the PCB. It should make sense on its own and having unconnected symbols on it that are only there for the PCB feels a bit icky to me. Obviously this is entirely opinion, so feel free to choose your own path.

**FURTHER UPDATE**: The issue of un-associated footprints is only an issue in slightly earlier versions of KiCAD. The *Update PCB from schematic* option has been improved and now gives the option not to *Delete extra footprints* and it's unchecked by default.

[065]: screenshots/065-new-pcb.png
[066]: screenshots/066-read-netlist.png
[067]: screenshots/067-netlist-read.png
[068]: screenshots/068-footprints-placed.png

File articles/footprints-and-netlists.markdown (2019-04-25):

# Footprints and Netlists

Now that we have a completed schematic we need to fill in some extra information to enable us to build a PCB. Each of the symbols that we have placed need to be associated with a *Footprint*. Footprints describe how a component will attach to a PCB. It defines how many *pads* there are, where they are and how they map to the component pins.

To set the footprint for a symbol, hover over it and press *E* to bring up the symbol properties.

Start by doing this with the SAMD10 MCU symbol:

Footprints Set

If you look at the *Footprint* field, you can see that it is already populated with a footprint. In this case, it's using the *Package_SO:SOIC-14_3.9x8.7mm_P1.27mm* footprint. Some symbols in the library already have a suitable footprint associated to them, so we can leave this one alone.

Let's look at the bypass capacitor symbol *C1* next. Bring the mouse over it and press *E*:

Footprint not set

Notice that the *Footprint* field is blank. Let's assign one.

Select the *Footprint* field by clicking on it in the list. On the right-hand side of the window click the *Browse Footprints* button to bring up the footprint browser:

Footprint Browser

Footprints are organised into categories, although these don't really match up with the symbol library categories.

For this project we're going to use Surface Mounted components, in *0805* size so let's browse to the *Capacitor_SMD* category and find the *Capacitor_SMD:C_0805_2012Metric_Pad1.15x1.40mm_HandSolder* footprint. Double-click it to select it and set it as the footprint for this symbol.

We need to set the footprints for each symbol (excluding the power net symbols - +3V3, GND and +BATT). To speed things up a little, we can copy and paste the field value between similar components. This schematic has 3 capacitors which will all have the same footprint. Select the text in the field and copy it, then you can press *E* over the other two capacitors and paste the value in.

Copy-pasting footprints

Do the reset pull-up resistor next. Hover over the symbol and press *E*, use the symbol browser to find an 0805 SMD resistor footprint:

Resistor footprint

Next up is the LED:

LED Footprint

Then the programming connector - we'll use a Through-hole footprint for this one so we can solder header pins in:

Programming footprint

Similarly, the GPIO connectors will be through-hole. Don't forget that there's 2 of those too!

GPIO footprint

Last is the button. I have about a million 6mm through-hole tactile switches, they're really common. I'm going to use the footprint for that switch:

Button footprint

With footprints all assigned to the symbols, the last step in designing our schematic is to generate a *Net list*. The net list describes how all of the components connect together and is used by the PCB design software to keep track of everything.

Choose *Generate Netlist File...* from the *Tools* menu:

Generate Netlist

Default settings are all fine, click the *Generate Netlist* button to create it. You'll be asked to save a file. Save it in the same folder with the rest of your project.

And that's it, we're finally ready to start designing the PCB.

[055]: screenshots/055-footprint-already-set.png
[056]: screenshots/056-footprint-not-set.png
[057]: screenshots/057-choosing-capacitor-footprint.png
[058]: screenshots/058-copy-footprint-value.png
[059]: screenshots/059-resistor-footprint.png
[060]: screenshots/060-LED-footprint.png
[061]: screenshots/061-programming-connector-footprint.png
[062]: screenshots/062-GPIO-footprint.png
[063]: screenshots/063-button-footprint.png
[064]: screenshots/064-generate-netlist.png

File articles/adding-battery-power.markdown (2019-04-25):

# Adding Battery Power

In this part we're going to add battery power to the board. Most modern MCUs can take a pretty wide range of input voltage to power them. According to the [SAMD10 Datasheet](http://ww1.microchip.com/downloads/en/devicedoc/atmel-42242-sam-d10_datasheet.pdf), ours is happy between 1.63V and 3.63V. This means if we want to power our board with a LiPo cell, we need to regulate the voltage down since a fully charged LiPo cell will typically have a voltage of 4.2V which is too high for our controller.

To start with, find a 'fresh' area of the schematic page:

Blank part of schematic

Press *A* to add a symbol and add a 1x2 generic connector. This will be for our battery.

Battery Connector

Place the symbol and hover over the symbol name *Conn_01x02* and press *E* to edit and rename it:

Rename connector

Alright, next we want to add a *Linear Regulator* symbol. There are lots of different types. I'm using [these AP7333 regulators](https://uk.rs-online.com/web/p/products/7513106/) which *don't* have a symbol in the library. **However**, do not despair - there are others in the library with the same pins. Lets check the [datasheet for the regulator](https://docs-emea.rs-online.com/webdocs/104a/0900766b8104adfd.pdf):

Regulator datasheet

This particular one comes in 2 flavours, *SOT23* and *SOT23R*. I have quite a lot of both from a previous project where I bought the wrong ones because I'd used the wrong symbol! We're going to use the *SOT23* package one, so we need to find a symbol that has the *IN*, *OUT* and *GND* pins numbered the same way.

The symbol browser has a *Regulator_Linear* category so what I did was click the first one in the list and then keep pressing the *down arrow* on my keyboard until I found a symbol with the pins laid out the same way as in the datasheet:

Linear regulator

Place the symbol and then edit the name field to match the part that we're using. There's no magic inside any of these symbols; as long as the pins match up to the device we can use the symbol.

Place regulator

More often than not these kinds of Integrated Circuit devices need some extra components to make them work properly and this Linear Regulator is no different. Luckily it's pretty simple and helpfully documented in the datasheet:

Typical Circuit

What this is essentially saying is that we need bypass capacitors on both the voltage input and voltage output. that's easy enough. Press *A* and add 2 capacitor symbols to the schematic:

Place Capacitors

Next press *P* and place 3 *GND* symbols, then use *W* to wire the circuit:

Wire circuit

Our regulator will take any voltage up to 6V and regulate it down to 3.3V (it will keep working down to 1V too, but it won't bring the voltage *UP*). This works great for LiPo cells, although some additional protection would ideally be needed to ensure the cell voltage doesn't drop too low as this can damage the cell (I'm not covering this in this guide though.)

To connect the 3.3V output to our board, we can simply connect it to the +3V3 power net. Press *P* to add a power symbol and add a +3V3 symbol and connect it to the top of the output pin:

Place 3v3

This is a good point to annotate our symbols and **save the schematic**

Annotate Schematic

The next step is also a little involved and requires us to think about *Footprints*. A symbol footprint describes how a symbol will appear on a PCB. It describes whether it's a surface mount component or through-hole, how many *pads* it has and where they go. The generic connector we used for the battery doesn't have any footprint associated with it - we have to choose one.

Let's say we want to add a [standard JST battery connector](https://uk.rs-online.com/web/p/pcb-headers/8201422/). This connector has a slot to ensure that the battery is connected the right way around but we don't really know which pin is positive and which is negative.

Here's a picture of the battery-end of the connector (male):

JST Connector

Tab at the top of the connector fits in to the slot on the PCB connector (female).

We can use the orientation of the red and black wires to help work out which pins are which on our generic connector, but we need to match the connector with a footprint first. Let's do that.

Hover your mouse over the battery connector symbol and press *E* to bring up the *Symbol Properties*:

Symbol Properties

One of the fields listed is for *Footprint* and it's currently blank. Click the *Browse Footprints* button to bring up the footprint browser. It might take a little while for the browser to load all of the footprints in, particularly the first time you open it. Be patient:

Footprint browser

The footprints are organised into categories, although these categories don't really match up with the symbol categories. There are so many different types of JST connector that they have their own category! Find that and then find the 1x2 2.00mm vertical option. Notice the drawing on the right shows us that the slot is pointing up and that pin 1 is on the left and pin 2 is on the right. Based on the picture of the LiPo battery above, we can see that Pin 1 is positive and 2 is ground.

**Caveat: I was able to find pictures of batteries connected both ways. A while back I plugged one of my LiPo batteries into a featherwing board I had and it went pop and let out the magic smoke. It appears that the wiring of 3.7v LiPo batteries is not standard and batteries bought from different places might be wired differently.**

I don't usually use connectors for my batteries - I tend to place flat pads and solder bare wires to the board. It's probably not the best way to do things but at least it avoids this issue. I'm not sure what the best solution here is. If you connect a battery with the wrong polarity to the linear regulator it goes pop and lets out the magic smoke. If you're lucky it does that faster than the MCU does. Still not an easy 'fuse' to have to replace (remember how I mentioned above that I have *both* the SOT23 and SOT23R versions of this regulator? Yeah...).

These are the stressful bits of designing your own boards. Let's press on...

Press *P* and add a +BATT power symbol the the schematic - connect it to *pin 1* of the battery connector.

Duplicate it and connect it to *pin 1* of the linear regulator too.

Battery net

Duplicate a *GND* symbol from somewhere and connect it to *pin 2*:

Battery wired

And that's it, our circuit is complete!

Completed Circuit

## Caveats

The whole battery wiring issue bothers me, and actually I wonder if you're better off *not* using connector with enforced orientation and simple marking on the board silkscreen (we'll get to that later) the polarity and simply solder in 2.00mm header pins. It's interesting that it only occurred to me when I wrote this that that might have been the reason for my featherwing board going pop!

It's worth considering adding a power switch to the mix - this could be added between the +BATT symbol and the connector pin. In my experience so far, finding nice power switches is actually harder than you think. ( [Here's a nice one](https://uk.rs-online.com/web/p/products/1238939/) )

As mentioned above, there's no protection against the battery over-discharging, although *most* LiPo cells do have that built in, it's probably not a good idea to rely on that.

You could also add a charging circuit that charges via USB, but to do that you've have to add a USB connector of some kind and I've avoided that for now because I kind of feel like if it's got a USB port on it, people expect it to be programmable via USB and that isn't something I feel like trying to do with this particular chip (I suppose it is *possible* via USART, but it's never going to be easy!)

[039]: screenshots/039-new-area-of-schematic.png
[040]: screenshots/040-battery-connector.png
[041]: screenshots/041-battery-connector-named.png
[042]: screenshots/042-linear-regulator-symbol.png
[043]: screenshots/043-regulator-placed.png
[044]: screenshots/044-datasheet-pinout.png
[045]: screenshots/045-datasheet-circuit.png
[046]: screenshots/046-capacitors-placed.png
[047]: screenshots/047-circuit-wired.png
[048]: screenshots/048-power-net-added.png
[049]: screenshots/049-symbols-annotated.png
[050]: screenshots/050-editing-symbol-properties.png
[051]: screenshots/051-choosing-footprint.png
[052]: screenshots/052-adding-battery-net.png
[053]: screenshots/053-battery-wired.png
[054]: screenshots/054-completed-circuit.png

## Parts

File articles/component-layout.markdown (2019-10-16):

# Laying out the Components

Now that we have our outline placed we need to arrange the components inside it. When laying out components on a board there are 2 key aspects that must be considered and balanced:

1. All the components will need to be connected together with traces in order for the board to function.
2. The board will need to make sense to the user in what ever context it will be used.

Even for a simple board like this, these two 'goals' will sometimes oppose each other. The nature of our board here means that #2 is going to impose the main *constraints*. Consider that we want to be able to plug this board into a breadboard. The position of the header pins is therefore important and this should be fairly obvious. Perhaps less obvious is that this also means that we need all of the components to be placed on the **top** of the board. We *could* get away with perhaps putting some of them on the bottom because the plastic spacers lift the PCB away from the breadboard, but it is certainly something that would have to be considered - imagine a design that includes electrolytic capacitors for example!

When laying out components, clever use of the built-in grid can be really helpful. In the top toolbar, just below the menubar there's a *Grid:* drop-down menu. It has a lot of options built-in and you can also add custom grids too. We want to choose the 2.5400mm grid in order to place the GPIO headers. This will ensure that they will fit into a breadboard.

Hover the mouse over one of the header footprints and press the *m* key. This will attach it to the mouse so you can move it. Place it with a click. You may also need to rotate them, which you can do with *r*.

Place them at the edges of the PCB as shown:

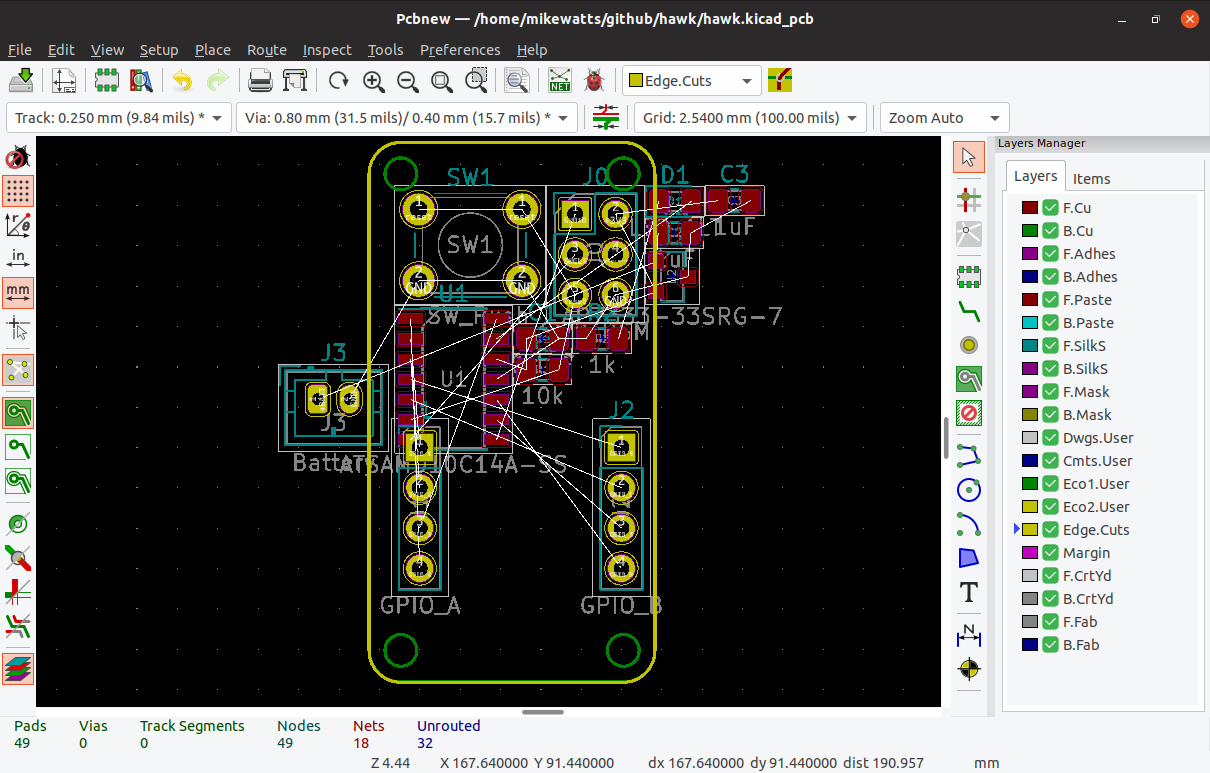
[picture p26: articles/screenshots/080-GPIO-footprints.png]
GPIO Headers


Notice that they aren't centred - don't worry about this at this stage, and don't change the grid so you can nudge them to fit nicely! We'll fix that later.

Move the MCU footprint to sit between them - you'll probably want to change the grid back to 0.1000mm and you can place it between the headers by eye (you're very unlikely to be able to solder a component within 0.1mm accuracy, so placing things by eye on a board like this is fine.)

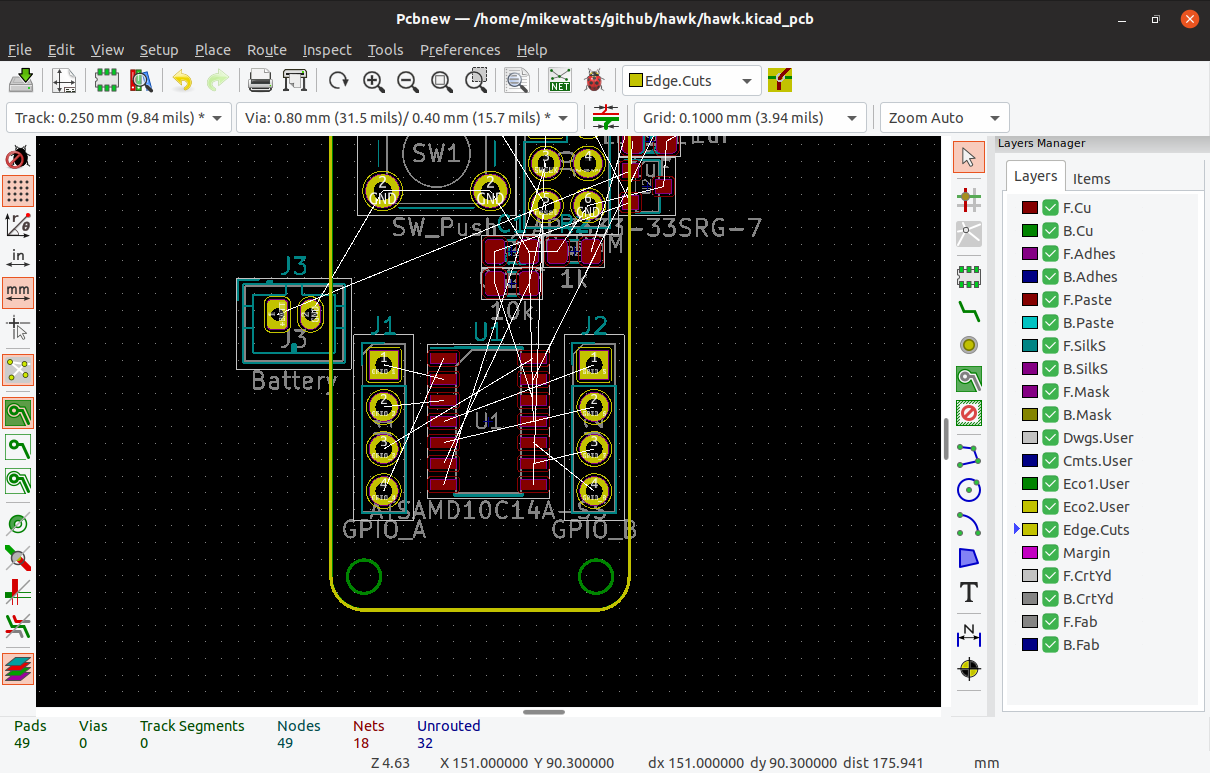
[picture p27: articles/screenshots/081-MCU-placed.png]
MCU placed


Now move the programming header and place it at the bottom of the board between the screw holes. Again, lining up by eye is fine.

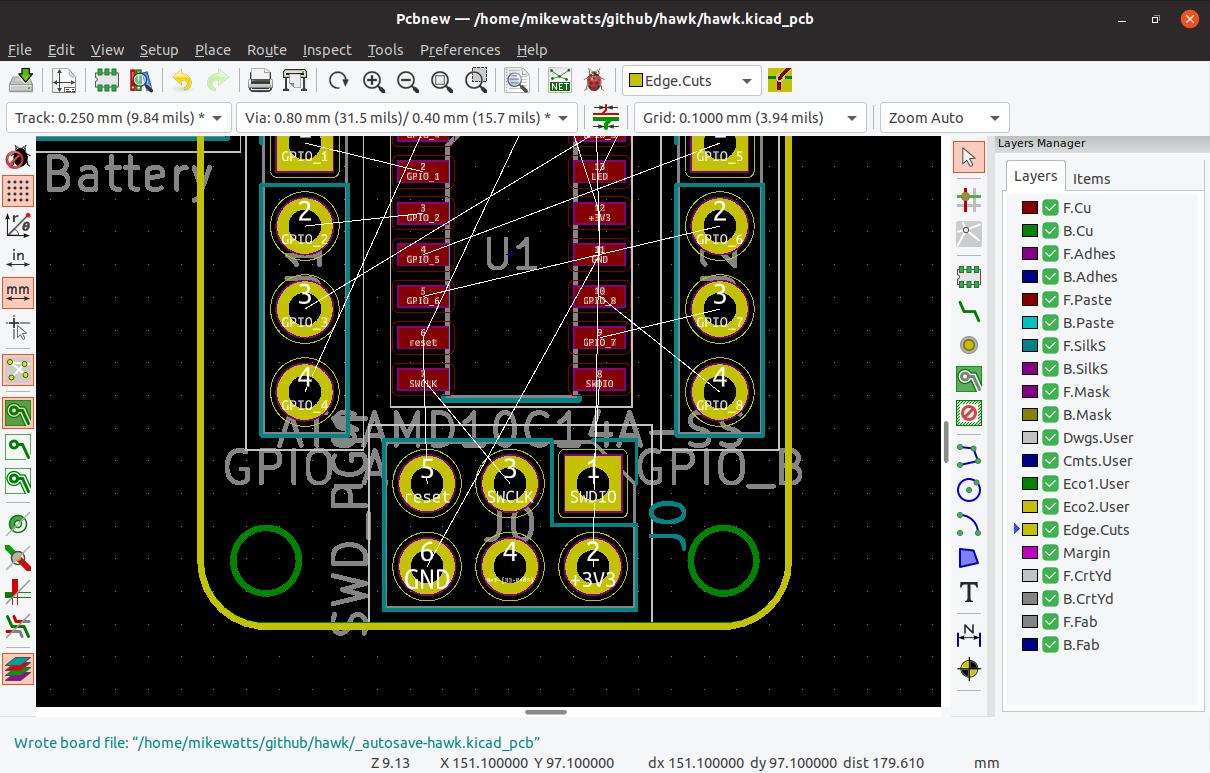
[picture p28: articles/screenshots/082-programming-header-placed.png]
Programming Header


You can see that the board is getting a little busy with all the layers shown. It's quite often worth turning off some of them at times to get a better view of what's going on. Turn off *ffab*:

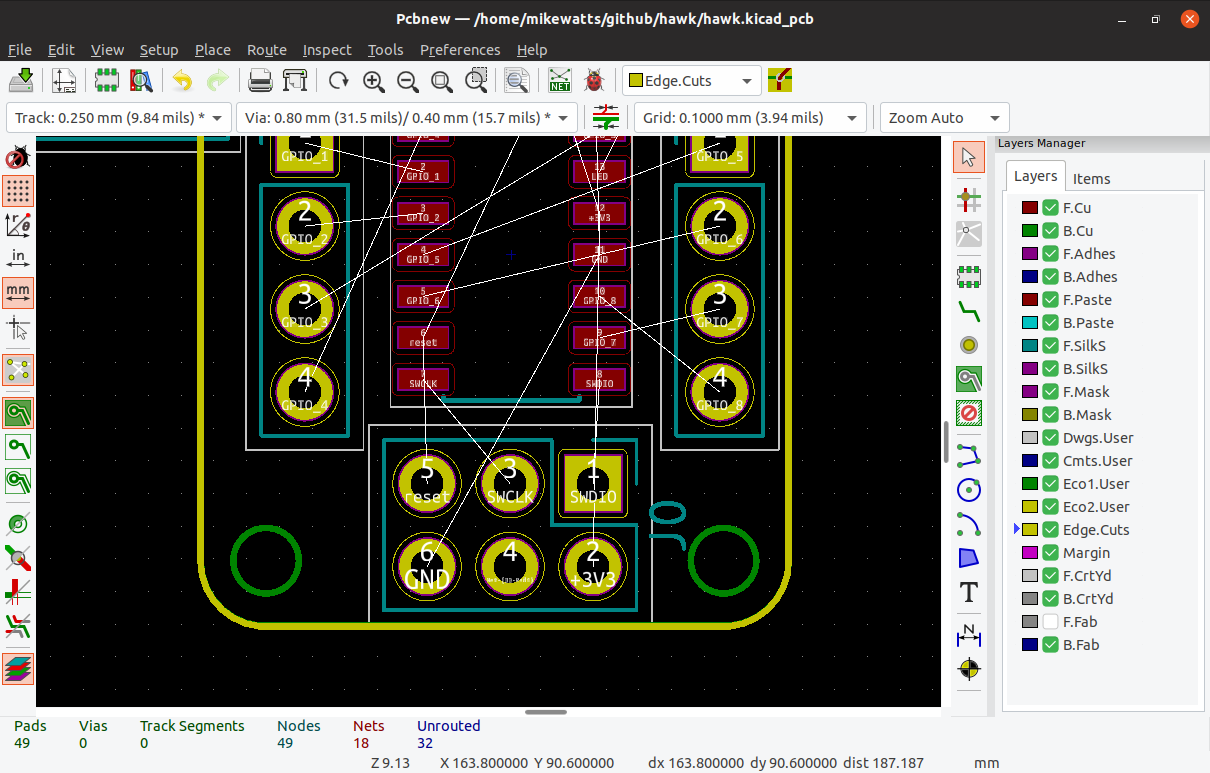
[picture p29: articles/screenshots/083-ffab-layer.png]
ffab layer


Move the rest of the component footprints into place. This is only a *rough* placing, because we still need to align the outline properly.

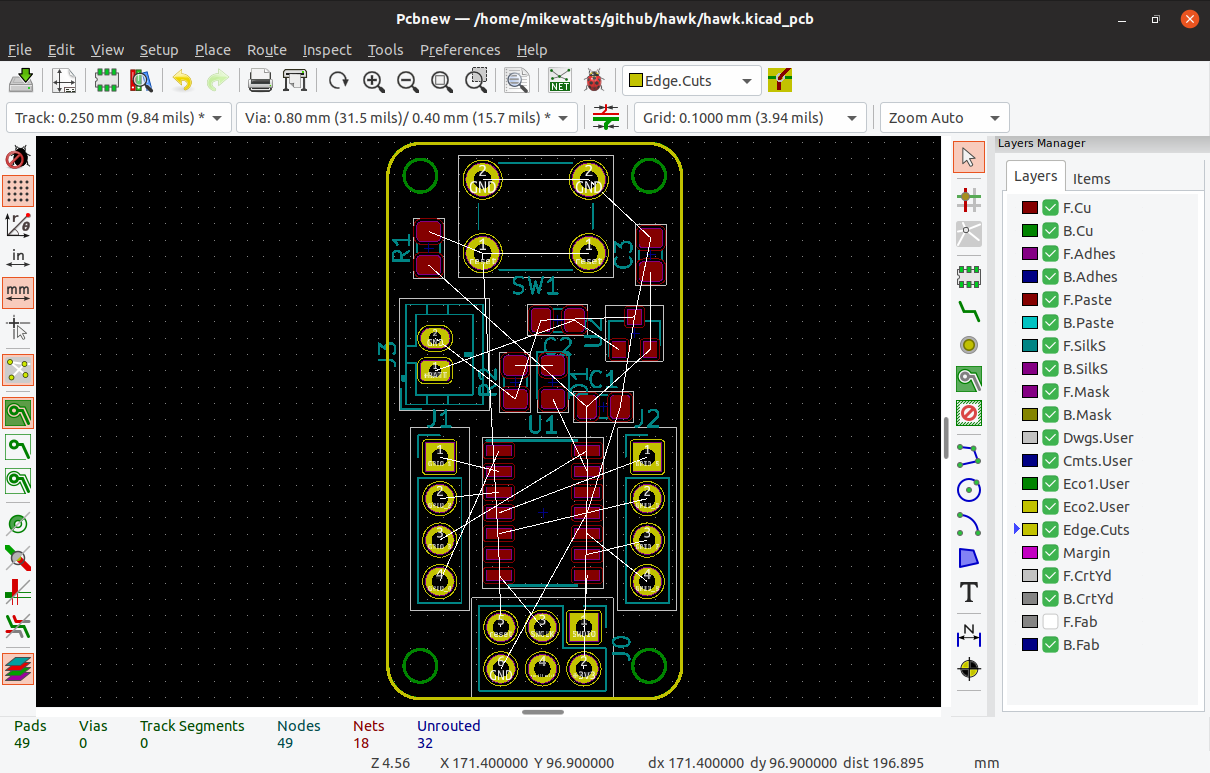
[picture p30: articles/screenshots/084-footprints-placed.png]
Footprints placed


Now, click and drag to draw a selection box around everything. Right-click and find the *Select* sub-menu (I've noticed that it moves around in the context menu, sometimes it's at the top, sometimes halfway down. I'm sure there's a reason but I've not worked it out yet.). Choose *Filter Selection*.

This little window allows us to specify specific classes of objects to keep selected. We want to move the board outline (and *only* the board outline).

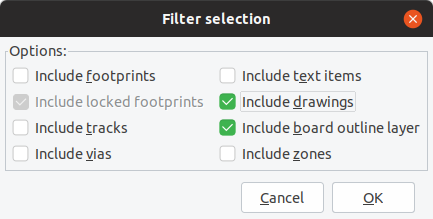
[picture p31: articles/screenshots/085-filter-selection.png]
Filter Selection


Notice that both *Board outlines* and *Drawings* is selected here - that's because we have the markings for where we want our screw holes to be, which we'll add later. Selecting and moving them together ensures they stay lined up.

Now you can move the board outline to properly centre the GPIO headers:

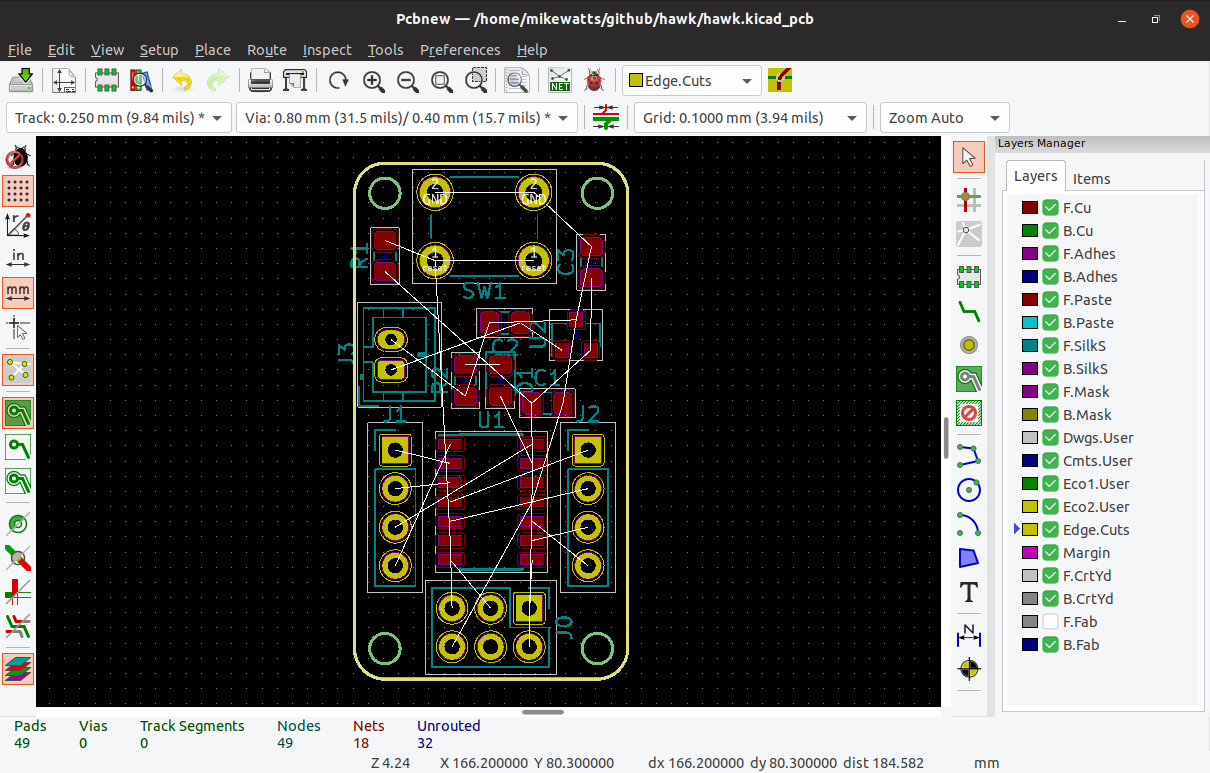
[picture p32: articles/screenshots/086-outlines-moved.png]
GPIO Headers Centred


Note that this throws a few other footprints off-centre, so we need to move those - **DON'T** move the GPIO headers independently they are our primary layout constraint because they have to interface with another device (breadboard).

Shuffle the last few components around to make them fit nicely

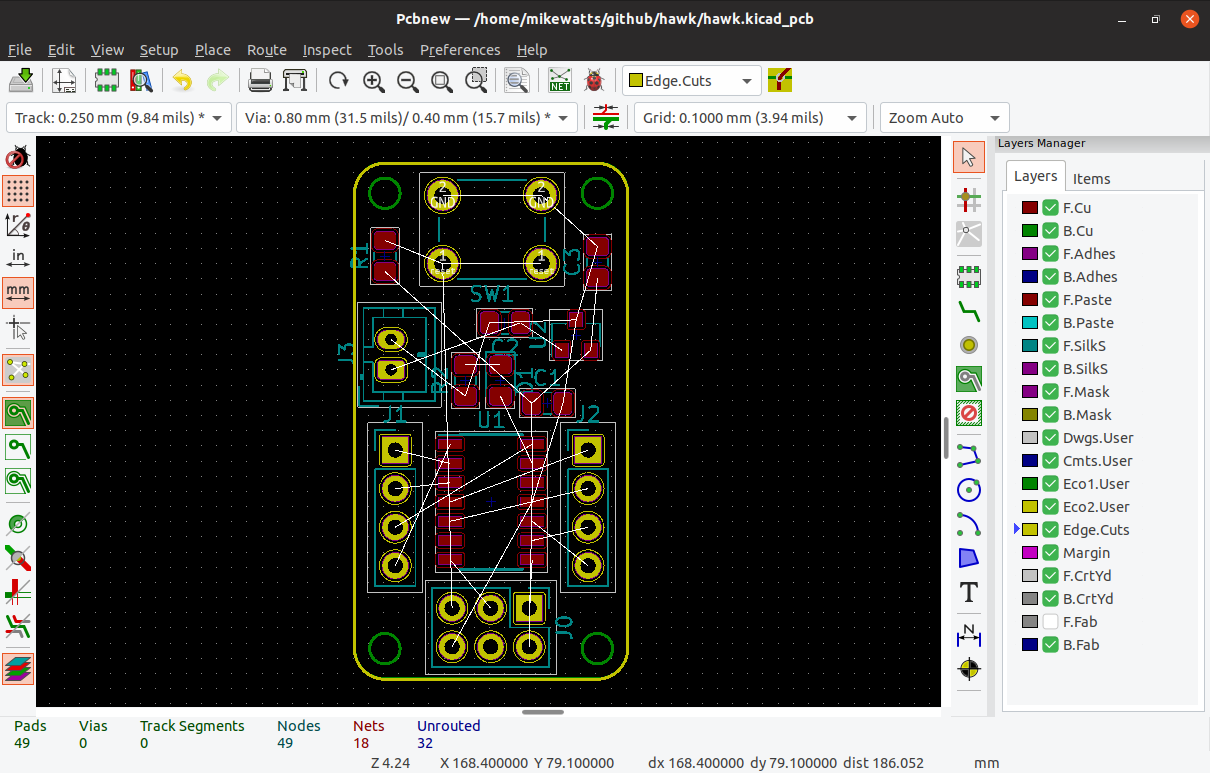
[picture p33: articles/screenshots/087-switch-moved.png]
Switch moved


You've probably noticed all the little white lines that connect the various footprint *pads* - this is called the *ratsnest* (and can be switched on and off in the toolbar on the left). PCBNew gets the information for these lines from the schematic. We will need to complete all of these connections using *traces* on the board. It's not unusual to have to move components around in order to make these connections easier to make. Laying out traces is probably the hardest part of designing a circuit board.

[080]: screenshots/080-GPIO-footprints.png
[081]: screenshots/081-MCU-placed.png
[082]: screenshots/082-programming-header-placed.png
[083]: screenshots/083-ffab-layer.png
[084]: screenshots/084-footprints-placed.png
[085]: screenshots/085-filter-selection.png
[086]: screenshots/086-outlines-moved.png
[087]: screenshots/087-switch-moved.png
[088]: screenshots/088-first-trace.png

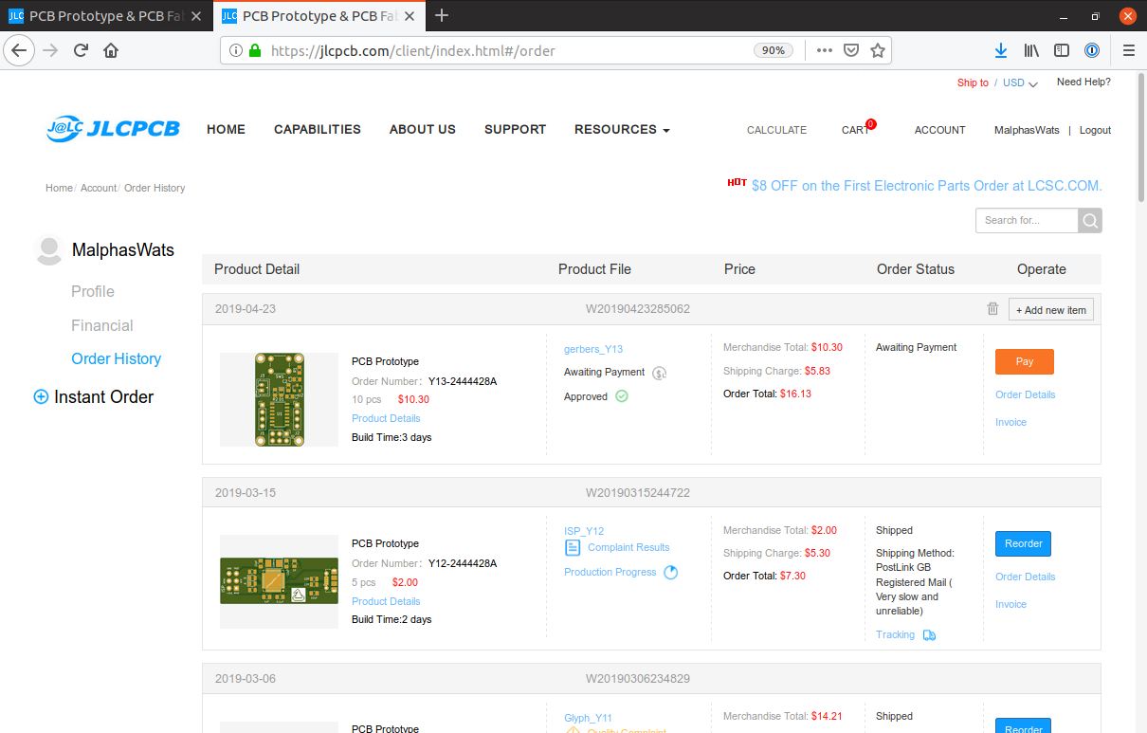
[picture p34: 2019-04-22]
articles/screenshots/128-order-details.png

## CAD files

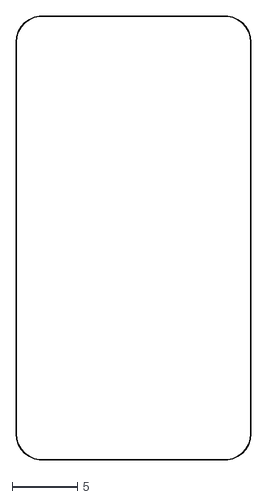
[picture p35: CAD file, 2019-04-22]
outline.dxf
18.0 x 34.0

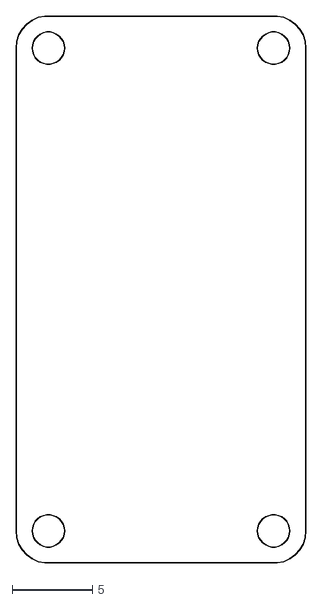
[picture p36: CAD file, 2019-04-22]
outline-screwholes.dxf
18.0 x 34.0

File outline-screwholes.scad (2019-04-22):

difference()
{

    minkowski()
    {
        square([14, 30], center=true);
        circle(r=2, $fn=30);
    }
    
    translate([7, 15]) circle(d=2.01, $fn=30);
    translate([-7, 15]) circle(d=2.01, $fn=30);
    translate([7, -15]) circle(d=2.01, $fn=30);
    translate([-7, -15]) circle(d=2.01, $fn=30);
}

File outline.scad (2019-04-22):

minkowski()
{
    square([14, 30], center=true);
    circle(r=2, $fn=30);
}

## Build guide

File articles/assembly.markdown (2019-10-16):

# Assembly

This section is short because I have no intention of writing a soldering tutorial! I am terrible at soldering but I've managed to make some fairly complex stuff just by having a go - SMD terrified me because I didn't want to waste a load of time and money messing up. In the end I treated myself to a cheap hot air rework station and had a go and it turned out to be a lot simpler than I expected. I'm still bad at it though.

I'm not going to assemble a whole board - just enough to get something I can play with.

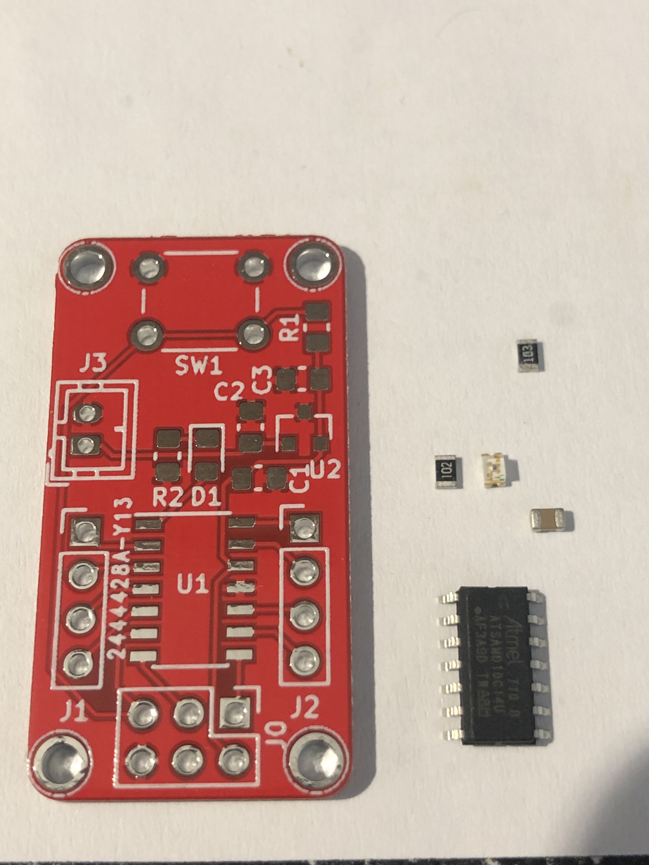
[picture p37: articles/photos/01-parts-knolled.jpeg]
Parts


Here you can see the glorious board we have been designing. I don't actually recommend that you make one of these - there are quite a few issues with it that I want to try and address in a future tutorial - but it does work and will serve my purpose of learning to program for SAMD chips.

Next I carefully splooged out some solder paste on the pads that I want to solder components to:

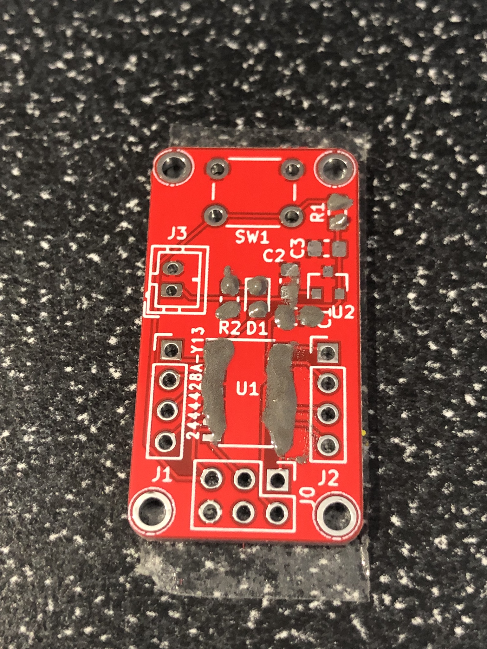
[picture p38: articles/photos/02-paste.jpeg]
Paste


When I first started thinking about Surface Mount soldering, I thought you had to be REALLY careful with how you applied the paste. I deliberately didn't bother making stencils for this board because I wanted to show that it's perfectly possible to assemble SMD boards without one.

You can see that I've made a bit of a mess up by the linear regulator IC, which is ok, I'm not planning to populate that part of the circuit.

Next I placed each component carefully - the 2 that *really* matter are the LED and the MCU - you have to make sure you orient them correctly. The MCU has a little spot on the plastic casing next to Pin 1, which goes at the top on our board. The LED will have a little symbol on the bottom which shows which way around it goes.

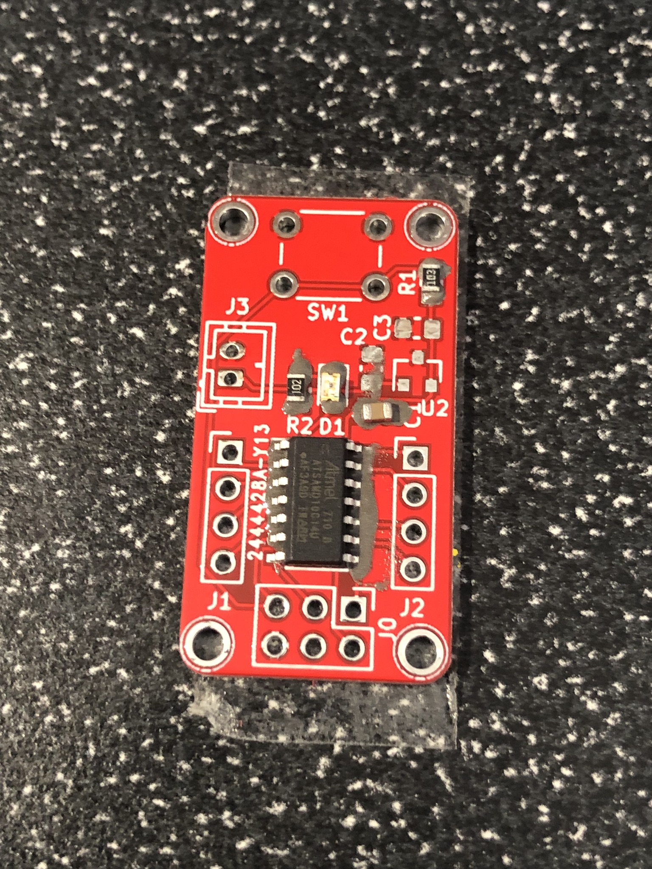
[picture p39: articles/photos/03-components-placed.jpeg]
Placed


Once all of the parts were in place, I shot hot air at it until the solder melted, everything stopped sliding around and the solder looked nice and shiny.

**Then I walked away and left it**.

Don't try moving it, it will take a while for the solder to cool and re-solidify and any movement during this time will knock components off their pads. Also the board itself is **HOT**.

You might also notice that I stuck the board to my desk with some double sided tape. I thought this was a really clever idea that would help me to place things without everything sliding all over the place. It turned out to be a **REALLY BAD IDEA**. The heat from the hot air gun made the adhesive on the tape melt and stick to everything that I didn't want it to - I still have a sticky patch on my desk. It took a lot of effort to get it off the bottom of the board. I have since [bought a nice little pcb holder thing](https://thepihut.com/products/adafruit-fully-adjustable-pcb-clamp-holder-ada3791).

Once it had cooled, I soldered some header pins to the programming header with a regular soldering iron.

Here it is with the [Blink example code loaded](https://github.com/MalphasWats/hawk/blob/master/blink/blink.c)

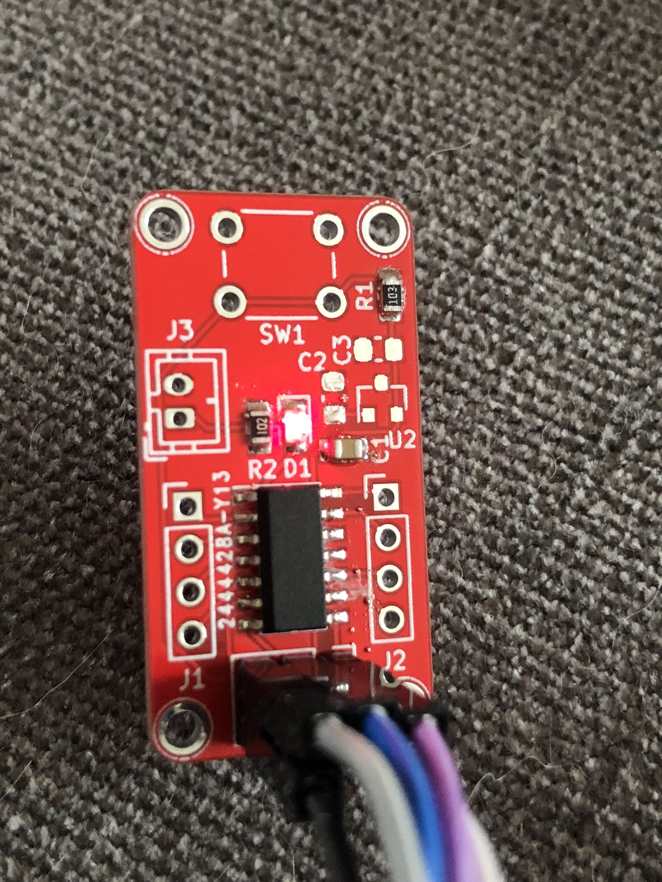
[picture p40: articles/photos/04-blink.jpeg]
Programmed


[01]: photos/01-parts-knolled.jpeg
[02]: photos/02-paste.jpeg
[03]: photos/03-components-placed.jpeg
[04]: photos/04-blink.jpeg

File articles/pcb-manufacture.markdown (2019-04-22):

# Manufacturing the PCB

Now that we have a completed board, it's time to send it off for manufacture.

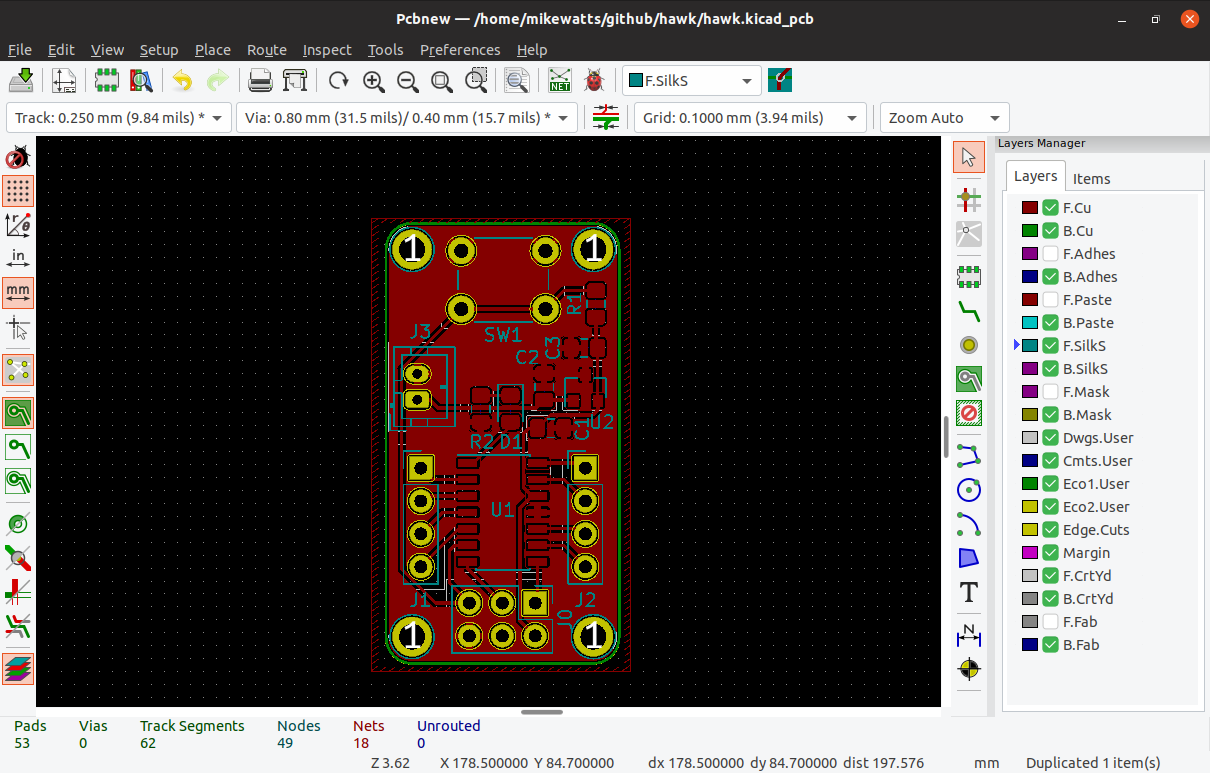
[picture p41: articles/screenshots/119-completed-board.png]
Completed Board


I use [JLCPCB](https://jlcpcb.com) for all of my projects at the moment. JLCPCB have offered to pay for this little project board to be produced and asked me to write a little bit about how I've found their service.

This is my 13th board with them and I've been really happy with the quality - one board had a small issue with the solder mask covering some pads and they fixed it and sent me replacements with no issues. I do this stuff as a hobby so it's definitely a bonus that the service is affordable.

First step is just to make a final DRC check to make sure everything checks out:

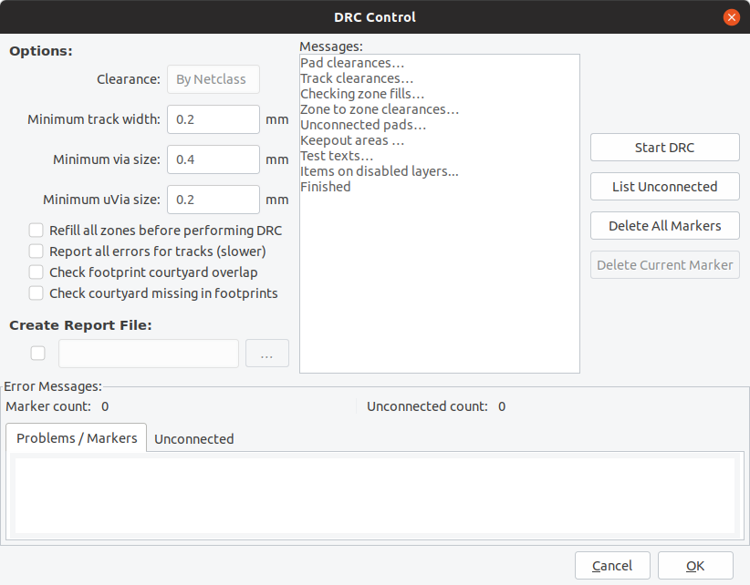
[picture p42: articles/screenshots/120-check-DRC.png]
DRC


The JLCPCB service requires that you upload Gerber files which KiCAD can produce. Click *File > Plot...* to bring up the plot pane:

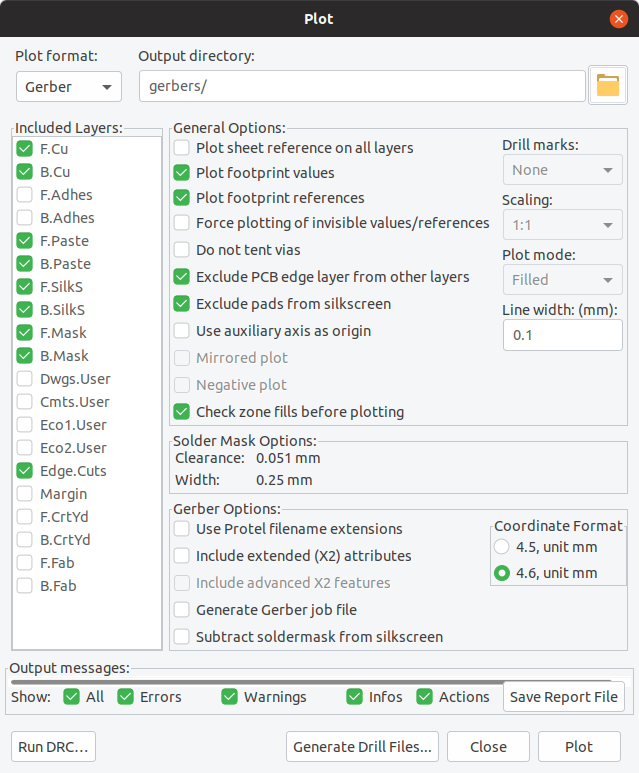
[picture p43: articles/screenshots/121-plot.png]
Plot


Make sure to choose a folder for the files to be generated into at the top. By default KiCAD selects the right set of layers and other settings, so just click *Plot* at the bottom to generate the Gerber files.

As well as Gerber files, JLCPCB need Drill files. Click the *Generate Drill Files...* button to bring up the Drill Files pane:

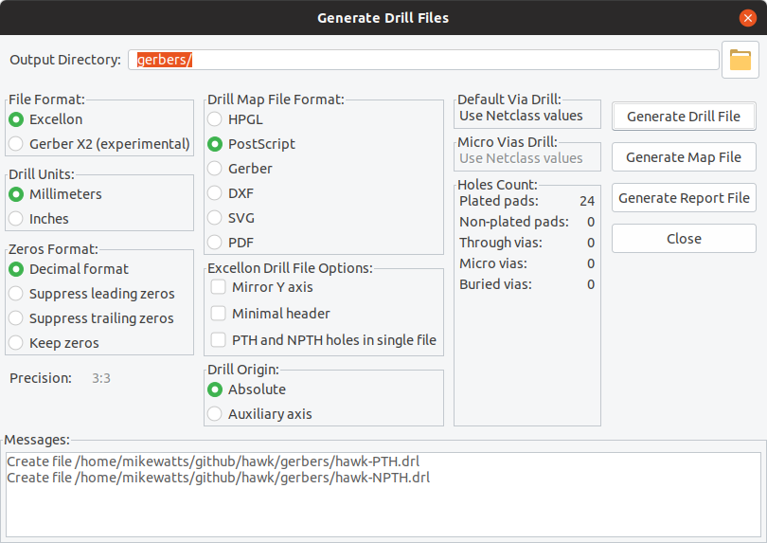
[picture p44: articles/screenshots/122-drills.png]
Drills


Choose *Millimeters* under the *Drill Units* heading, make sure that the output directory is the same as for the Gerber files and press the *Generate Drill File*.

The Gerber files need to be uploaded as a zip file. The *Plot* output folder can be zipped up:

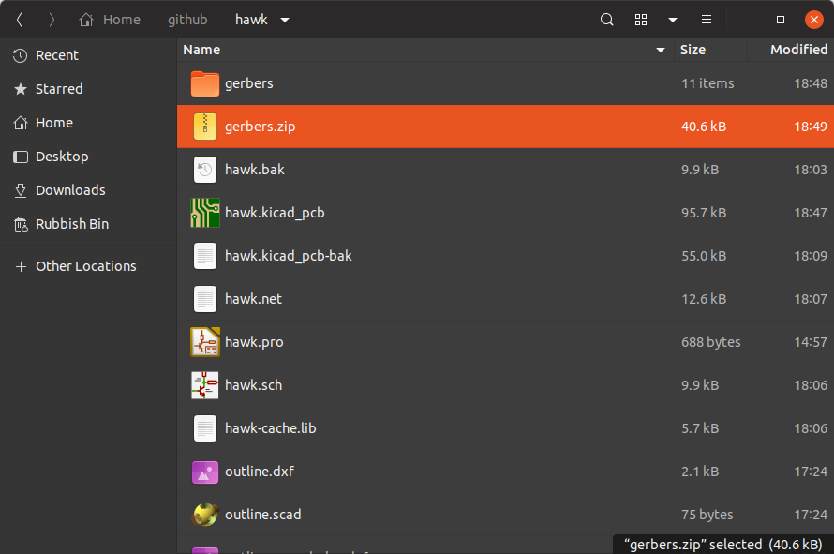
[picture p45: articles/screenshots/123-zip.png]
Zip


Next load up the [JLCPCB website](https://jlcpcb.com) and click the *Quote Now* button:

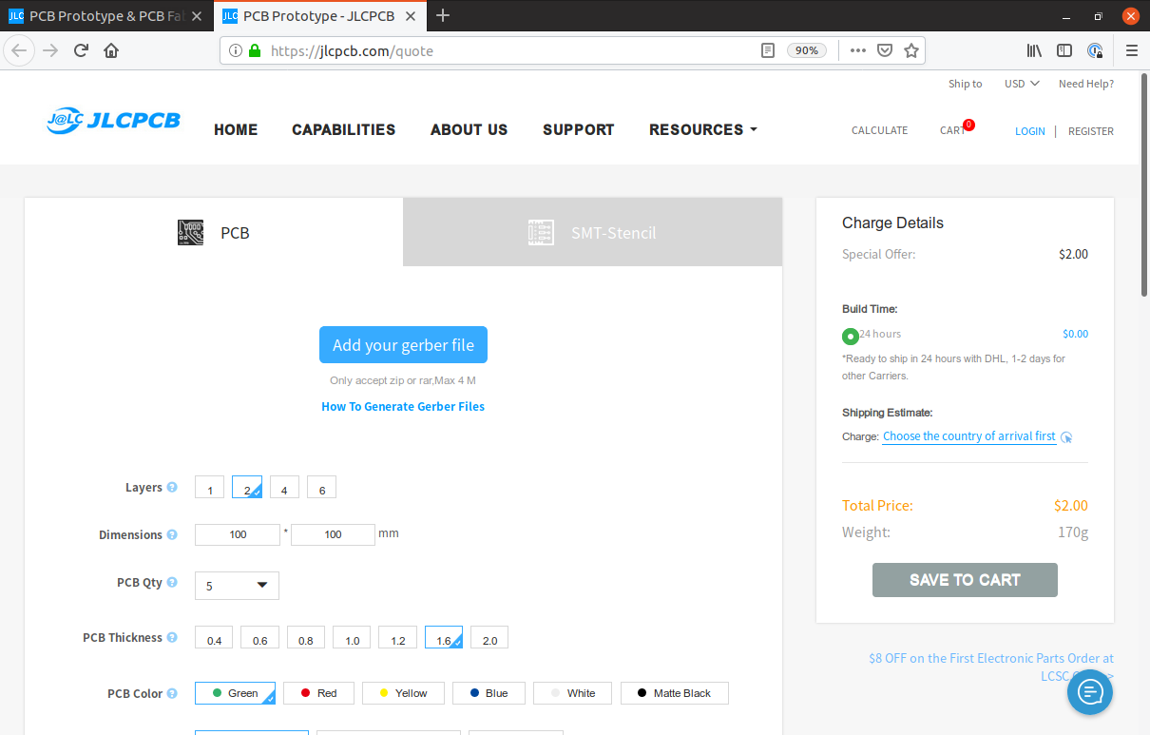
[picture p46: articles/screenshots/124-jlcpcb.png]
JCLPCB


Click on *Add your gerber file* and choose the zip file containing the Gerber files. They will be uploaded and scanned and a nice little picture of what the board will look like will be generated:

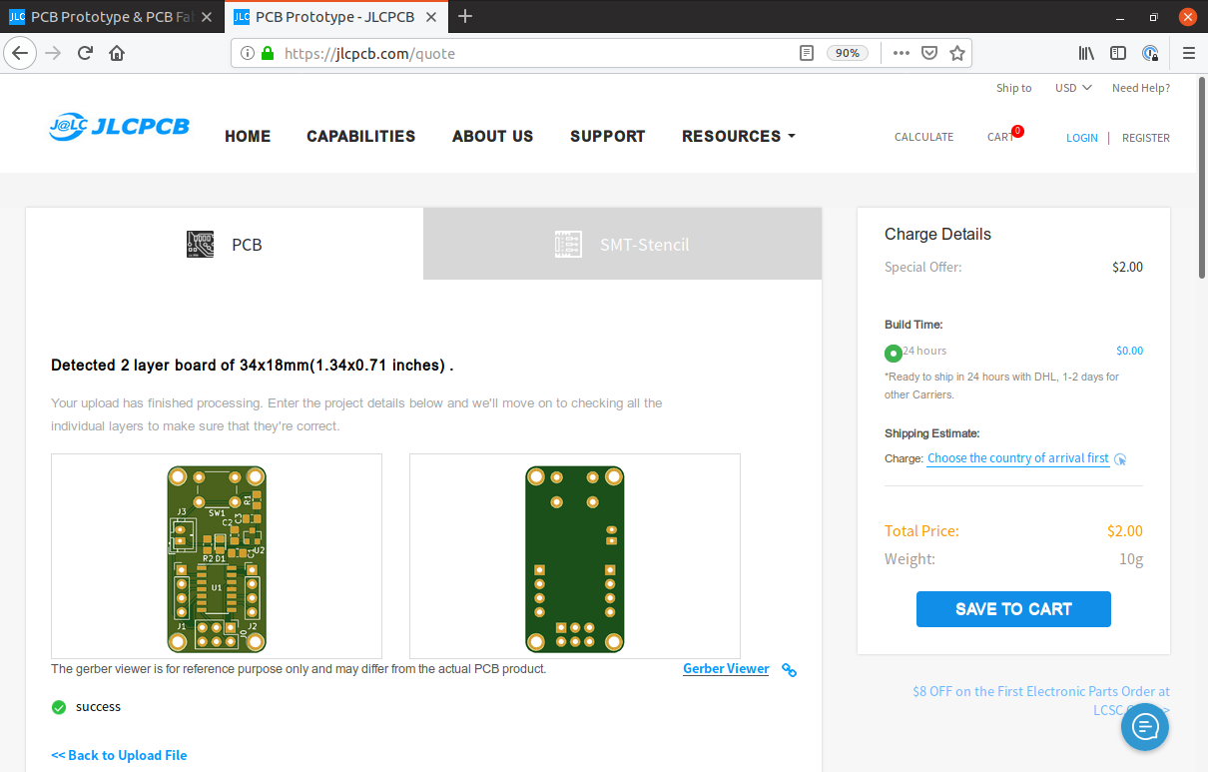
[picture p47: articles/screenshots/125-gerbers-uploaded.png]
Gerbers Uploaded


Scroll down to the options for your board:

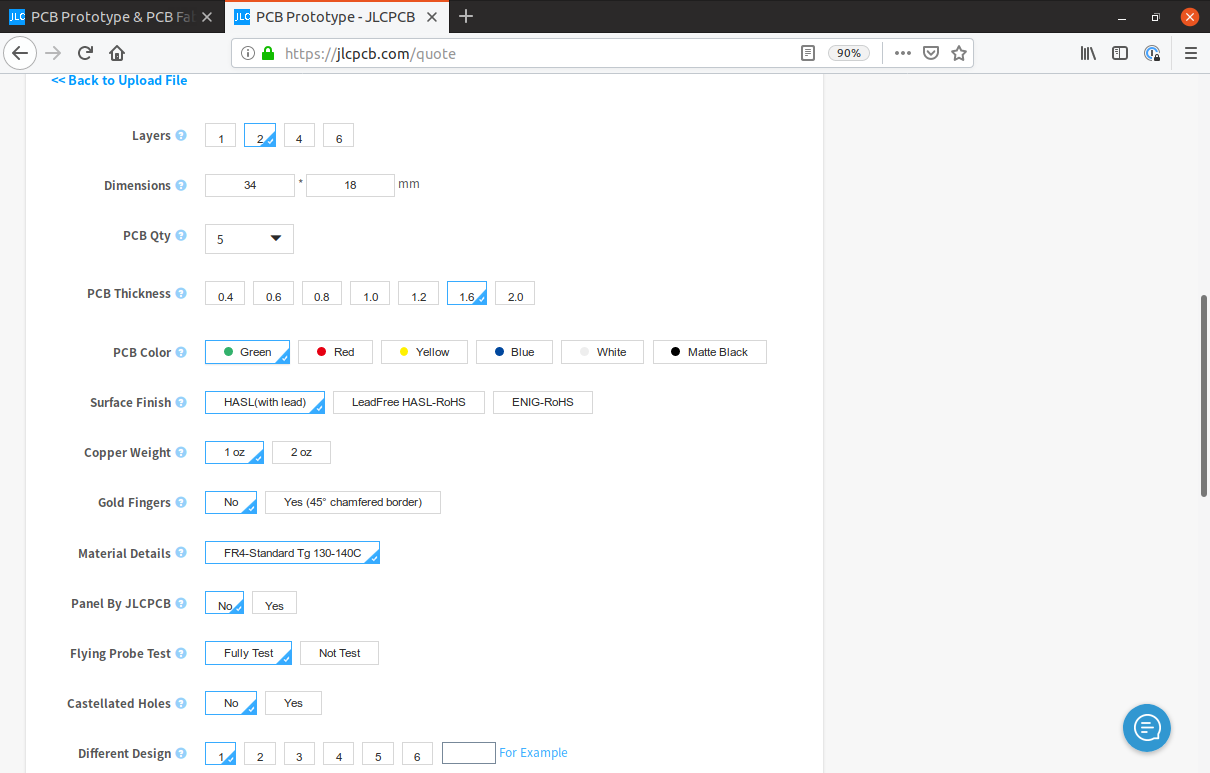
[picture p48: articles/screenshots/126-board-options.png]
Board options


Here you can choose things like board thickness, solder mask colour (which is now a free option!) and the pad surface finish. The rest of the settings here can be safely ignored until you need them.

Once you're happy with your options click *Save to cart*.

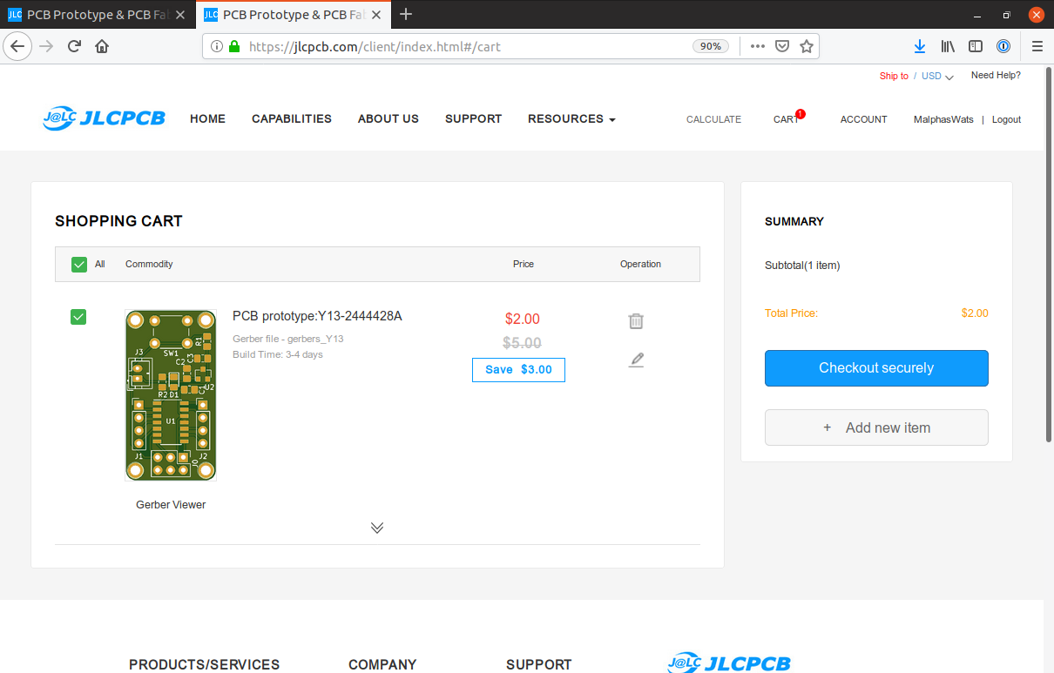
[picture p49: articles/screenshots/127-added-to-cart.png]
Save to cart


You'll be asked to create an account and pay, once you've done that, you can track your order's progress. Depending on which delivery option you choose, your order will arrive 1-3 weeks later neatly boxed and ready for assembly!

[119]: screenshots/119-completed-board.png
[120]: screenshots/120-check-DRC.png
[121]: screenshots/121-plot.png
[122]: screenshots/122-drills.png
[123]: screenshots/123-zip.png
[124]: screenshots/124-jlcpcb.png
[125]: screenshots/125-gerbers-uploaded.png
[126]: screenshots/126-board-options.png
[127]: screenshots/127-added-to-cart.png
[128]: screenshots/128-order-details.png

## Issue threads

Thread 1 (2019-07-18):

No mention of ERC ?

f6fvy, 2019-07-18:
Nice job, but you don't mention (and don't use) the ERC (Electrical Rules Checking) in schematics. Which it pretty useful to detect obvious mistakes.

BTW, it would probably fail because you don't use any power flag.

MalphasWats, 2019-09-21:
You're right actually - I do use it usually, I'm not sure why I didn't cover it. I will try and add a bit about it at some point.

The DRC check does pass for this board, and there are power flags on there.

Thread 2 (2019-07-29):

Typo in "Creating the schematic"

zaprodk, 2019-07-29:
"The nice thing about tutorials is you're entirely free to do it you're own way!"
Should be 'your' in the end, not 'you're'

MalphasWats, 2019-09-21:
Thanks! Fixed.

Closed 2019-09-21.

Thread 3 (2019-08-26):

Programming the board?

twopoint718, 2019-08-26:
It looks like "Programming" is coming up an a future installment, but in the mean time could you comment on what sort of debugger/programmer one would need to be able to program this board? For example, would a J-Link (SWD) work?

And thanks for the very clear intro to KiCad!

JPatGH, 2019-08-29:
I have an assembled board ready to program.
Could anyone comment of how this is done?

twopoint718, 2019-08-30:
It may be overkill, but I've picked up a J-LINK EDU which (should) work with pretty much any Cortex-M μC. While googling around I saw that the black magic probe may also work as well. I'll update this issue when I can confirm with my own hardware.

twopoint718, 2019-09-02:
@GHvsBB Okay, I can confirm that I can program the board using a J-Link (EDU model). I used the SWD debugging connection. You'll need to connect up the header pins as follows:

Header pin|Function|JTAG 20-pin connector
-|-|-
1 | SWDIO | 7
2|+3.3V|1 (VTRef)
3|SWCLK|9
-|N/C|-
5|RESET|15
6|GND|4

I'd imagine that there's some kind of breakout/adapter but I just used jumper wires. The VTRef connection is so that the debugger knows the board voltage level (3.3V). There's a separate +5V pin (no. 19) that could be used to supply power to the board (since the board has a voltage regulator), but I didn't use it.

MalphasWats, 2019-09-21:
Sorry - I'm not used to having issues in my repos and totally didn't notice your question!

I used a cheap ST-Link V2 clone I found on eBay to program it with SWD.

I am planning to write this up at some point, although it ended up being more complicated than I expected because it required OpenOCD to be patched because of the cheap programmer!

twopoint718, 2019-09-21:
If you're interested, I could write up what I did and run that by you. I was thinking of blogging that anyway.

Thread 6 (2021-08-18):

Problem with v5.1.10 release build and Chapter9

pike2k, 2021-08-18:
Nice guide, I thank you for it.

The 4 holes we made in OpenSCAD to use as guides for step9 (Silkscreen) has some issues in the version I'm using of PCBNew.

The issue is that the Eco1.User layer is not visible (no transparancy) through the black center of the footprint (2mm Plated Test Point footprint).
Thus the Eco1.User layer can't be used proper as a guide.

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

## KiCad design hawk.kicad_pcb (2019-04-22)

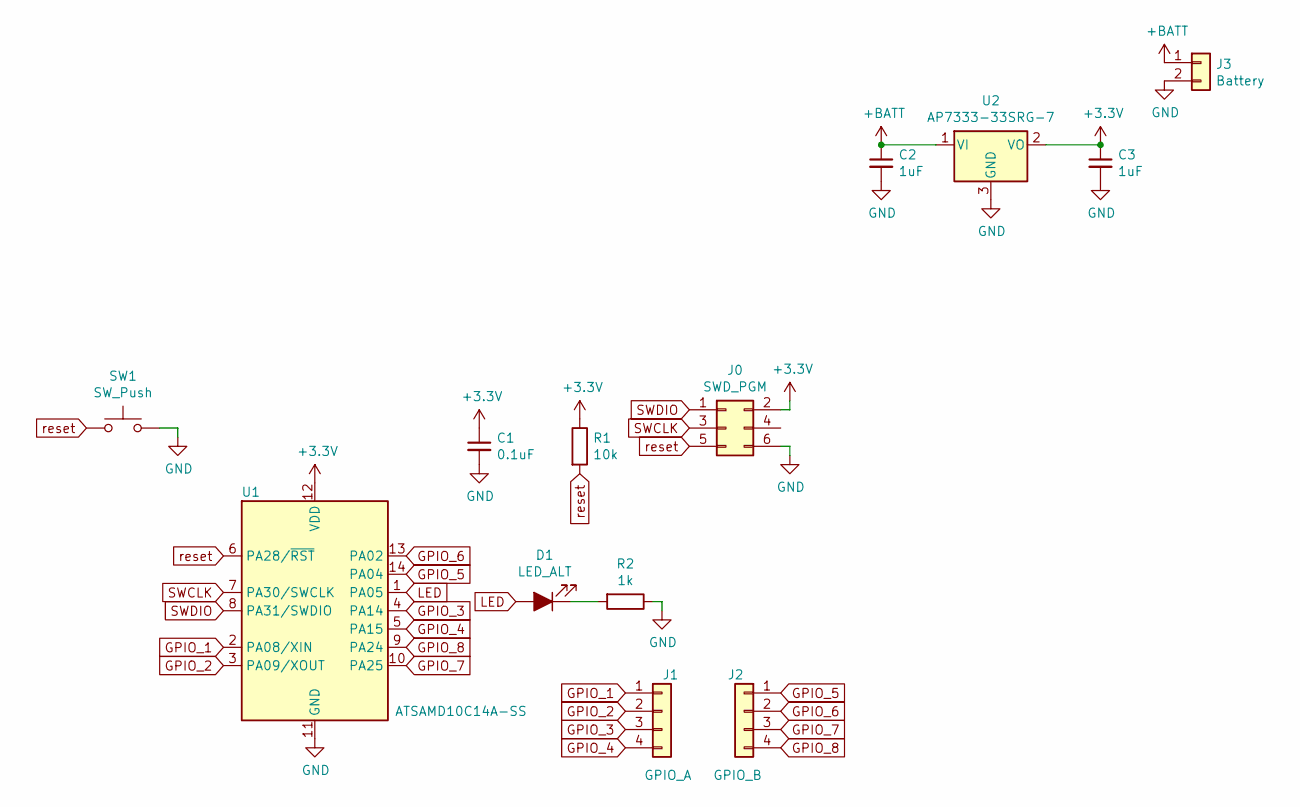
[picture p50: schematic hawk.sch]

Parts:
C1: 0.1uF; C_0805_2012Metric_Pad1.15x1.40mm_HandSolder
C2, C3: 1uF; C_0805_2012Metric_Pad1.15x1.40mm_HandSolder
D1: LED_ALT; LED_0805_2012Metric_Pad1.15x1.40mm_HandSolder
J0: SWD_PGM; PinHeader_2x03_P2.54mm_Vertical
J1: GPIO_A; PinHeader_1x04_P2.54mm_Vertical
J2: GPIO_B; PinHeader_1x04_P2.54mm_Vertical
J3: Battery; JST_PH_B2B-PH-K_1x02_P2.00mm_Vertical
R1: 10k; R_0805_2012Metric_Pad1.15x1.40mm_HandSolder
R2: 1k; R_0805_2012Metric_Pad1.15x1.40mm_HandSolder
SW1: SW_Push; SW_PUSH_6mm
U1: ATSAMD10C14A-SS; SOIC-14_3.9x8.7mm_P1.27mm
U2: AP7333-33SRG-7; SOT-23

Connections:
+3V3: C1.1, C3.1, J0.2, R1.1, U1.12 (VDD), U2.2 (VO)
+BATT: C2.1, J3.1, U2.1 (VI)
GND: C1.2, C2.2, C3.2, J0.6, J3.2, R2.1, SW1.2, U1.11 (GND), U2.3 (GND)
GPIO_1: J1.1, U1.2 (PA08/XIN)
GPIO_2: J1.2, U1.3 (PA09/XOUT)
GPIO_3: J1.3, U1.4 (PA14)
GPIO_4: J1.4, U1.5 (PA15)
GPIO_5: J2.1, U1.14 (PA04)
GPIO_6: J2.2, U1.13 (PA02)
GPIO_7: J2.3, U1.10 (PA25)
GPIO_8: J2.4, U1.9 (PA24)
LED: D1.2 (A), U1.1 (PA05)
unnamed: D1.1 (K), R2.2
SWCLK: J0.3, U1.7 (PA30/SWCLK)
SWDIO: J0.1, U1.8 (PA31/SWDIO)
reset: J0.5, R1.2, SW1.1, U1.6 (PA28/~RST)

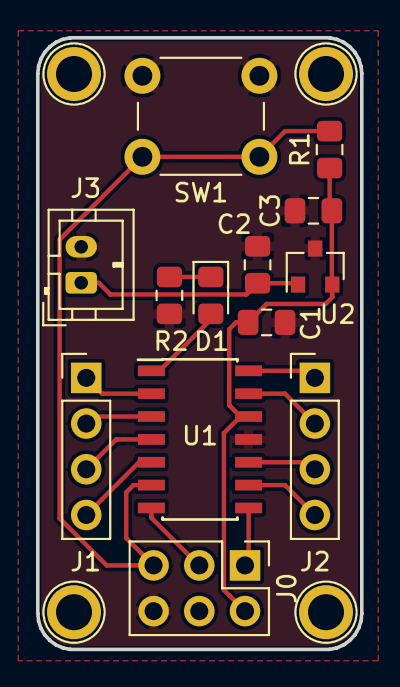
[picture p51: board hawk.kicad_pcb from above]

Board: 2 copper layers, 18.0 x 34.0 mm, 13 parts (0 on the bottom side), 16 nets.

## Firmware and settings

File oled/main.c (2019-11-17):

#include "samd10c14a.h"
#include "ASCII.h"

#define LED_PIN 5

#define CLOCK           15  //4
#define MOSI            14  //2
#define DATA_COMMAND    24
#define CHIP_SELECT     8
#define RESET           25

#define SCREEN_WIDTH 128
#define SCREEN_HEIGHT 64
#define SCREEN_ROWS 8

#define SSD1351_CMD_SETCOLUMN 		0x15
#define SSD1351_CMD_SETROW    		0x75
#define SSD1351_CMD_WRITERAM   		0x5C
#define SSD1351_CMD_READRAM   		0x5D
#define SSD1351_CMD_SETREMAP 		0xA0
#define SSD1351_CMD_STARTLINE 		0xA1
#define SSD1351_CMD_DISPLAYOFFSET 	0xA2
#define SSD1351_CMD_DISPLAYALLOFF 	0xA4
#define SSD1351_CMD_DISPLAYALLON  	0xA5
#define SSD1351_CMD_NORMALDISPLAY 	0xA6
#define SSD1351_CMD_INVERTDISPLAY 	0xA7
#define SSD1351_CMD_FUNCTIONSELECT 	0xAB
#define SSD1351_CMD_DISPLAYOFF 		0xAE
#define SSD1351_CMD_DISPLAYON     	0xAF
#define SSD1351_CMD_PRECHARGE 		0xB1
#define SSD1351_CMD_DISPLAYENHANCE	0xB2
#define SSD1351_CMD_CLOCKDIV 		0xB3
#define SSD1351_CMD_SETVSL 		0xB4
#define SSD1351_CMD_SETGPIO 		0xB5
#define SSD1351_CMD_PRECHARGE2 		0xB6
#define SSD1351_CMD_SETGRAY 		0xB8
#define SSD1351_CMD_USELUT 		0xB9
#define SSD1351_CMD_PRECHARGELEVEL 	0xBB
#define SSD1351_CMD_VCOMH 		0xBE
#define SSD1351_CMD_CONTRASTABC		0xC1
#define SSD1351_CMD_CONTRASTMASTER	0xC7
#define SSD1351_CMD_MUXRATIO            0xCA
#define SSD1351_CMD_COMMANDLOCK         0xFD
#define SSD1351_CMD_HORIZSCROLL         0x96
#define SSD1351_CMD_STOPSCROLL          0x9E
#define SSD1351_CMD_STARTSCROLL         0x9F

uint8_t buffer[SCREEN_WIDTH * SCREEN_ROWS];

void delay(uint16_t n)
{
    uint8_t i;

    for (;n >0; n--)
    {
        for (i=0;i<100;i++)
            __asm("nop");
    }
}

/*void shift_out(uint8_t data)
{
    for (uint8_t i=0; i < 8; i++)
    {
        if ( data & (1 << (7 - i)) )
        {
            REG_PORT_OUT0 |= 1 << MOSI;
        }
        else
        {
            REG_PORT_OUT0 &= ~(1 << MOSI);
        }

        REG_PORT_OUT0 |= 1 << CLOCK;      // HIGH
        REG_PORT_OUT0 &= ~(1 << CLOCK);   // LOW
    }
}*/

void init_spi(void)
{
   PM->APBCMASK.bit.SERCOM0_ = 1;
    GCLK->CLKCTRL.reg = GCLK_CLKCTRL_CLKEN | GCLK_CLKCTRL_ID_SERCOM0_CORE;
    while(GCLK->STATUS.bit.SYNCBUSY);
    const SERCOM_SPI_CTRLA_Type ctrla = {
      .bit.DORD = 0, // MSB first
      .bit.CPHA = 0, // Mode 0
      .bit.CPOL = 0,
      .bit.FORM = 0, // SPI frame
      .bit.DIPO = 3, // MISO on PAD[3]
      .bit.DOPO = 0, // MOSI on PAD[0], SCK on PAD[1], SS_ on PAD[2]
      .bit.MODE = 3  // Master
    };
    SERCOM0->SPI.CTRLA.reg = ctrla.reg;
    const SERCOM_SPI_CTRLB_Type ctrlb = {
      .bit.RXEN = 0,   // RX enabled (not!)
      .bit.MSSEN = 0,  // HW SS (off)
      .bit.CHSIZE = 0 // 8-bit
    };
    SERCOM0->SPI.CTRLB.reg = ctrlb.reg;

    SERCOM0->SPI.BAUD.reg = 1;//0; // Rate is clock / 2

    // Mux for SERCOM1 PA16,PA17,PA18,PA19
    const PORT_WRCONFIG_Type wrconfig = {
      .bit.WRPINCFG = 1,
      .bit.WRPMUX = 1,
      .bit.PMUX = MUX_PA14C_SERCOM0_PAD0,
      .bit.PMUXEN = 1,
      .bit.HWSEL = 0,
      .bit.PINMASK = (uint16_t)((PORT_PA14 | PORT_PA15))// | PORT_PA04))//>>16)// | PORT_PA18 | PORT_PA19) >> 16)
    };
    PORT->Group[0].WRCONFIG.reg = wrconfig.reg;

    SERCOM0->SPI.CTRLA.bit.ENABLE = 1;
    while(SERCOM0->SPI.SYNCBUSY.bit.ENABLE);

    //REG_PORT_OUT0 |= (1<<LED_PIN);
}

//uint8_t shift_out(uint8_t data)
void shift_out(uint8_t data)
{
    while(SERCOM0->SPI.INTFLAG.bit.DRE == 0);
    SERCOM0->SPI.DATA.reg = data;
    while(SERCOM0->SPI.INTFLAG.bit.TXC == 0);
    //REG_PORT_OUT0 ^= (1<<LED_PIN);
    //return SERCOM0->SPI.DATA.reg;
}

void initialise_oled(void)
{
    REG_PORT_OUT0 &= ~(1 << CHIP_SELECT);                // LOW (Enabled)

    REG_PORT_OUT0 |= 1 << RESET;          // HIGH
    delay(10);
    REG_PORT_OUT0 &= ~(1 << RESET);       // LOW
    delay(10);
    REG_PORT_OUT0 |= 1 << RESET;          // HIGH
    delay(10);

    REG_PORT_OUT0 &= ~(1 << DATA_COMMAND);        // LOW (Command Mode)

    shift_out(0xAE);         // DISPLAYOFF

    shift_out(0xD5);         // SETDISPLAYCLOCKDIV
    shift_out(0x80);         // the suggested ratio 0x80

    shift_out(0xA8 );        // SSD1306_SETMULTIPLEX
    shift_out(SCREEN_HEIGHT - 1);

    shift_out(0xD3 );        // SETDISPLAYOFFSET
    shift_out(0x0);          // no offset
    shift_out(0x40  | 0x0);  // SETSTARTLINE line #0

    shift_out(0x8D);        // CHARGEPUMP
    shift_out(0x14);         // Not External Vcc

    shift_out(0x20 );        // MEMORYMODE
    shift_out(0x00);         // 0x0 act like ks0108
    shift_out(0xA0  | 0x1);  // SEGREMAP
    shift_out(0xC8 );        // COMSCANDEC


    shift_out(0xDA);        // SETCOMPINS
    shift_out(0x12);

    shift_out(0x81 );        // SETCONTRAST
    shift_out(0xCF);         // Not External Vcc


    shift_out(0xD9 );        // SETPRECHARGE
    shift_out(0xF1);         // Not External Vcc

    shift_out(0xDB);        // SETVCOMDETECT
    shift_out(0x40);

    shift_out(0xA4 );        // DISPLAYALLON_RESUME
    shift_out(0xA6 );        // NORMALDISPLAY

    //shift_out(0x2E );        // DEACTIVATE_SCROLL

    shift_out(0xAF);         // DISPLAYON

    REG_PORT_OUT0 |= 1 << DATA_COMMAND;      // Data Mode
}

void clear_buffer(void)
{
    for (uint16_t i=0 ; i<SCREEN_WIDTH*SCREEN_ROWS ; i++)
        buffer[i] = 0x00;
}

void draw( void )
{
    for (uint16_t i=0 ; i<SCREEN_WIDTH*SCREEN_ROWS ; i++)
        shift_out(buffer[i]);
}

void draw_tile(const uint8_t *tile, int16_t x, int16_t y)
{
    /* is the tile actually visible */
    if (x < -7 || x >= SCREEN_WIDTH || y < -7 || y >= SCREEN_HEIGHT)
        return;

    int16_t y_ = y;

    if (y < 0)
        y_ = 0-y;

    int16_t tile_start = ((y_ >> 3) * SCREEN_WIDTH) + x;

    uint8_t y_offset_a = y & 7; // y % 8
    uint8_t y_offset_b = 8-y_offset_a;

    uint8_t tile_index = 0;
    int8_t tile_dir = 1;
    uint8_t tile_width = 8;
    if (x < 0)
    {
        tile_start -= x;
        tile_index = 0-x;
        tile_width -= tile_index;
    }

    if (x > SCREEN_WIDTH-8)
    {
        tile_width = SCREEN_WIDTH-x;
    }

    if (y < 0)
    {
        y_offset_a = 8;
        y_offset_b = 0-y;
        tile_start -= SCREEN_WIDTH;
    }

    if (y > SCREEN_HEIGHT-8)
    {
        y_offset_b = 8;
    }

    for(uint8_t tile_offset=0 ; tile_offset<tile_width ; tile_offset++, tile_index+=tile_dir)
    {
        if (y_offset_a < 8)
        {
            buffer[tile_start+tile_offset] = tile[tile_index] << y_offset_a;
        }
        if (y_offset_b < 8)
        {
            buffer[tile_start+SCREEN_WIDTH+tile_offset] = tile[tile_index] >> y_offset_b;
        }
    }
}

void draw_int(int16_t n, uint8_t width, int16_t x, int16_t y)
{
    //TODO: Negative numbers
    int32_t n_;
    for (uint8_t i=0 ; i<width ; i++)
    {
        n_ = (6554*(int32_t)n)>>16;
        draw_tile(&DIGITS[(n - (n_*10))*8], x+((width-i-1)*8), y);
        n = (int16_t)n_;
    }
}

//https://electronics.stackexchange.com/questions/332569/how-to-configure-atmel-sam-d20-for-internal-48mhz-clock-source
void set_clock()
{
    // Change the timing of the NVM access
    NVMCTRL->CTRLB.bit.RWS = NVMCTRL_CTRLB_RWS_HALF_Val; // 1 wait state for operating at 2.7-3.3V at 48MHz.

    // Enable the bus clock for the clock system.
    PM->APBAMASK.bit.GCLK_ = 1; //true;

    // Initialise the DFLL to run in closed-loop mode at 48MHz
    // 1. Make a software reset of the clock system.
    GCLK->CTRL.bit.SWRST = 1; //true;
    while (GCLK->CTRL.bit.SWRST && GCLK->STATUS.bit.SYNCBUSY) {};
    // 2. Make sure the OCM8M keeps running.
    SYSCTRL->OSC8M.bit.ONDEMAND = 0;
    // 3. Set the division factor to 64, which reduces the 1MHz source to 15.625kHz
    GCLK->GENDIV.reg =
        GCLK_GENDIV_ID(3) | // Select generator 3
        GCLK_GENDIV_DIV(64); // Set the division factor to 64
    // 4. Create generic clock generator 3 for the 15KHz signal of the DFLL
    GCLK->GENCTRL.reg =
        GCLK_GENCTRL_ID(3) | // Select generator 3
        GCLK_GENCTRL_SRC_OSC8M | // Select source OSC8M
        GCLK_GENCTRL_GENEN; // Enable this generic clock generator
    while (GCLK->STATUS.bit.SYNCBUSY) {}; // Wait for synchronization
    // 5. Configure DFLL with the
    GCLK->CLKCTRL.reg =
        GCLK_CLKCTRL_ID_DFLL48 | // Target is DFLL48M
        GCLK_CLKCTRL_GEN(3) | // Select generator 3 as source.
        GCLK_CLKCTRL_CLKEN; // Enable the DFLL48M
    while (GCLK->STATUS.bit.SYNCBUSY) {}; // Wait for synchronization
    // 6. Workaround to be able to configure the DFLL.
    SYSCTRL->DFLLCTRL.bit.ONDEMAND = 0;  //false
    while (!SYSCTRL->PCLKSR.bit.DFLLRDY) {}; // Wait for synchronization.
    // 7. Change the multiplication factor.
    SYSCTRL->DFLLMUL.bit.MUL = 3072; // 48MHz / (1MHz / 64)
    SYSCTRL->DFLLMUL.bit.CSTEP = 1; // Coarse step = 1
    SYSCTRL->DFLLMUL.bit.FSTEP = 1; // Fine step = 1
    while (!SYSCTRL->PCLKSR.bit.DFLLRDY) {}; // Wait for synchronization.
    // 8. Start closed-loop mode
    SYSCTRL->DFLLCTRL.reg |=
        SYSCTRL_DFLLCTRL_MODE | // 1 = Closed loop mode.
        SYSCTRL_DFLLCTRL_QLDIS; // 1 = Disable quick lock.
    while (!SYSCTRL->PCLKSR.bit.DFLLRDY) {}; // Wait for synchronization.
    // 9. Clear the lock flags.
    //SYSCTRL->INTFLAG.bit.DFLLLCKC = 1;
    //SYSCTRL->INTFLAG.bit.DFLLLCKF = 1;
    //SYSCTRL->INTFLAG.bit.DFLLRDY = 1;
    // 10. Enable the DFLL
    SYSCTRL->DFLLCTRL.bit.ENABLE = 1;//true;
    while (!SYSCTRL->PCLKSR.bit.DFLLRDY) {}; // Wait for synchronization.
    // 11. Wait for the fine and coarse locks.
    while (!SYSCTRL->INTFLAG.bit.DFLLLCKC && !SYSCTRL->INTFLAG.bit.DFLLLCKF) {};
    // 12. Wait until the DFLL is ready.
    while (!SYSCTRL->INTFLAG.bit.DFLLRDY) {};

    // Switch the main clock speed.
    // 1. Set the divisor of generic clock 0 to 0
    GCLK->GENDIV.reg =
        GCLK_GENDIV_ID(0) | // Select generator 0
        GCLK_GENDIV_DIV(0);
    while (GCLK->STATUS.bit.SYNCBUSY) {}; // Wait for synchronization
    // 2. Switch generic clock 0 to the DFLL
    GCLK->GENCTRL.reg =
        GCLK_GENCTRL_ID(0) | // Select generator 0
        GCLK_GENCTRL_SRC_DFLL48M | // Select source DFLL
        GCLK_GENCTRL_IDC | // Set improved duty cycle 50/50
        GCLK_GENCTRL_GENEN; // Enable this generic clock generator
    while (GCLK->STATUS.bit.SYNCBUSY) {}; // Wait for synchronization
}

void writeCommand(uint8_t data)
{
    REG_PORT_OUT0 &= ~(1 << DATA_COMMAND);        // LOW (Command Mode)

    shift_out(data);
}

void writeData(uint8_t data)
{
    REG_PORT_OUT0 |= 1 << DATA_COMMAND;      // Data Mode

    shift_out(data);
}

void init1351()
{
    REG_PORT_OUT0 &= ~(1 << CHIP_SELECT);                // LOW (Enabled)

    REG_PORT_OUT0 |= 1 << RESET;          // HIGH
    delay(50);
    REG_PORT_OUT0 &= ~(1 << RESET);       // LOW
    delay(50);
    REG_PORT_OUT0 |= 1 << RESET;          // HIGH
    delay(50);

    // Initialization Sequence
    writeCommand(SSD1351_CMD_COMMANDLOCK);  // set command lock
    writeData(0x12);
    writeCommand(SSD1351_CMD_COMMANDLOCK);  // set command lock
    writeData(0xB1);

    writeCommand(SSD1351_CMD_DISPLAYOFF);  		// 0xAE

    writeCommand(SSD1351_CMD_CLOCKDIV);  		// 0xB3
    //writeCommand(0xF1);  						// 7:4 = Oscillator Frequency,
                                                //3:0 = CLK Div Ratio (A[3:0]+1 = 1..16)
    //writeData(0xF1);
    writeData(0x00);


    writeCommand(SSD1351_CMD_MUXRATIO);
    writeData(127);

    writeCommand(SSD1351_CMD_SETREMAP);
    writeData(0x74);

    writeCommand(SSD1351_CMD_SETCOLUMN);
    writeData(0x00);
    writeData(0x7F);
    writeCommand(SSD1351_CMD_SETROW);
    writeData(0x00);
    writeData(0x7F);

    writeCommand(SSD1351_CMD_STARTLINE); 		// 0xA1
    writeData(0x0);

    writeCommand(SSD1351_CMD_DISPLAYOFFSET); 	// 0xA2
    writeData(0x0);

    writeCommand(SSD1351_CMD_SETGPIO);
    writeData(0x00);

    writeCommand(SSD1351_CMD_FUNCTIONSELECT);
    writeData(0x01); // internal (diode drop)
    //writeData(0x01); // external bias

//    writeCommand(SSSD1351_CMD_SETPHASELENGTH);
//    writeData(0x32);

    writeCommand(SSD1351_CMD_PRECHARGE);  		// 0xB1
    //writeCommand(0x32);
    writeData(0x32);

    writeCommand(SSD1351_CMD_VCOMH);  			// 0xBE
    //writeCommand(0x05);
    writeData(0x05);

    writeCommand(SSD1351_CMD_NORMALDISPLAY);  	// 0xA6

    writeCommand(SSD1351_CMD_CONTRASTABC);
    writeData(0xC8);
    writeData(0x80);
    writeData(0xC8);

    writeCommand(SSD1351_CMD_CONTRASTMASTER);
    writeData(0x0F);

    writeCommand(SSD1351_CMD_SETVSL );
    writeData(0xA0);
    writeData(0xB5);
    writeData(0x55);

    writeCommand(SSD1351_CMD_PRECHARGE2);
    writeData(0x01);

    writeCommand(SSD1351_CMD_DISPLAYON);		//--turn on oled panel

    writeCommand(SSD1351_CMD_WRITERAM);

    REG_PORT_OUT0 ^= (1<<LED_PIN);
}


int main()
{
    set_clock();

    //REG_PORT_DIR0 |= (1<<CLOCK) | (1<<MOSI) | (1<<DATA_COMMAND) | (1<<CHIP_SELECT) | (1<<RESET) | (1<<LED_PIN);
    REG_PORT_DIR0 |= (1<<DATA_COMMAND) | (1<<CHIP_SELECT) | (1<<RESET) | (1<<LED_PIN);
    uint8_t i = 0;

    init_spi();

    //initialise_oled();
    init1351();
    REG_PORT_OUT0 &= ~(1<<LED_PIN);
    //REG_PORT_OUT0 |= (1<<LED_PIN);

    //SERCOM0->SPI.BAUD.reg = 0;//0; // Rate is clock / 2
    //SERCOM0->SPI.CTRLA.bit.ENABLE = 1;
    //while(SERCOM0->SPI.SYNCBUSY.bit.ENABLE);

    REG_PORT_OUT0 |= 1 << DATA_COMMAND;      // Data Mode



        //REG_PORT_OUT0 |= (1 << CHIP_SELECT);                // Hi (disabled)
    uint16_t col = 0;

    //          RED   GREEN  BLUE
    // Colours xxxxx xxxxxx xxxxx

    uint8_t ct[] = {0x00, 0xf0};
    uint8_t cb[] = {0x0f, 0x00};

    uint8_t cnt = 0;
    uint8_t sx = 0;
    uint8_t sy = 0;

    while(1)
    {
        //clear_buffer();

        //draw_int(255-i, 3, 12*8, 6*8);
        //draw_int(i++, 3, 8, 8);
        //draw();

        //for (uint16_t i=0 ; i=128*128 ; i++)
        //{
        //    shift_out(0xff);
        //    shift_out(0xff);
        //}

        for (uint8_t y = 0 ; y < 128 ; y++)
        {
            for (uint8_t x = 0 ; x < 128 ; x++)
            {
                col = 0;
                if (y >= sy && y < sy+10 && x >= sx && x <= sx+10)
                {
                    col = 1;
                }

                while(SERCOM0->SPI.INTFLAG.bit.DRE == 0);
                SERCOM0->SPI.DATA.reg = ct[col];
                //while(SERCOM0->SPI.INTFLAG.bit.TXC == 0);

                //while(SERCOM0->SPI.INTFLAG.bit.DRE == 0);
                SERCOM0->SPI.DATA.reg = cb[col];
            }
        }

        sx += 4;
        if (sx > 128-10)
        {
            sy+=10;
            sx=0;
        }
        if (sy > 128-10)
        {
            sy = 0;
        }

        /*for (uint16_t i=0 ; i<128*128 ; i++)
        {
            //shift_out(cb[col]);
            //shift_out(ct[col]);

            while(SERCOM0->SPI.INTFLAG.bit.DRE == 0);
            SERCOM0->SPI.DATA.reg = ct[col];
            //while(SERCOM0->SPI.INTFLAG.bit.TXC == 0);

            //while(SERCOM0->SPI.INTFLAG.bit.DRE == 0);
            SERCOM0->SPI.DATA.reg = cb[col];
            //while(SERCOM0->SPI.INTFLAG.bit.TXC == 0);
        }
        cnt += 1;
        if (cnt == 40)
        {
            col += 1;
            if (col > 1)
                col=0;
            cnt = 0;
        }*/

        //delay(100);
    }
}

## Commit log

2019-04-22 initial implementation
    [hawk-B.Cu.gbr, hawk-B.Mask.gbr, hawk-B.Paste.gbr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]
2019-04-22 renamed all schematic screenshots
2019-04-22 pcb page template
2019-04-22 board manfuacture writeup
2019-04-24 Written up to power symbols.
2019-04-24 Switch and LED circuit
2019-04-24 Completed creating schematic part 1
2019-04-25 added text to connect to regulator
2019-04-25 added link to switch
2019-05-02 added info about update pcb from schematic
2019-07-13 bitbang spi oled test
2020-03-04 added pcb capabilites image reference
